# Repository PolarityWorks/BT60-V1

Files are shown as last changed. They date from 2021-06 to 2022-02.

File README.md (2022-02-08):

# BT60 V1

This is the repository of the design files for the Polarity Works [BT60 V1](https://www.polarityworks.com/bt60) containing both schematic and layout files for the soldered and hotswap variants

The files were created in Autodesk Eagle V9.6.2, in the event you do not have a licence for this software we also provide the schematics in PDF format

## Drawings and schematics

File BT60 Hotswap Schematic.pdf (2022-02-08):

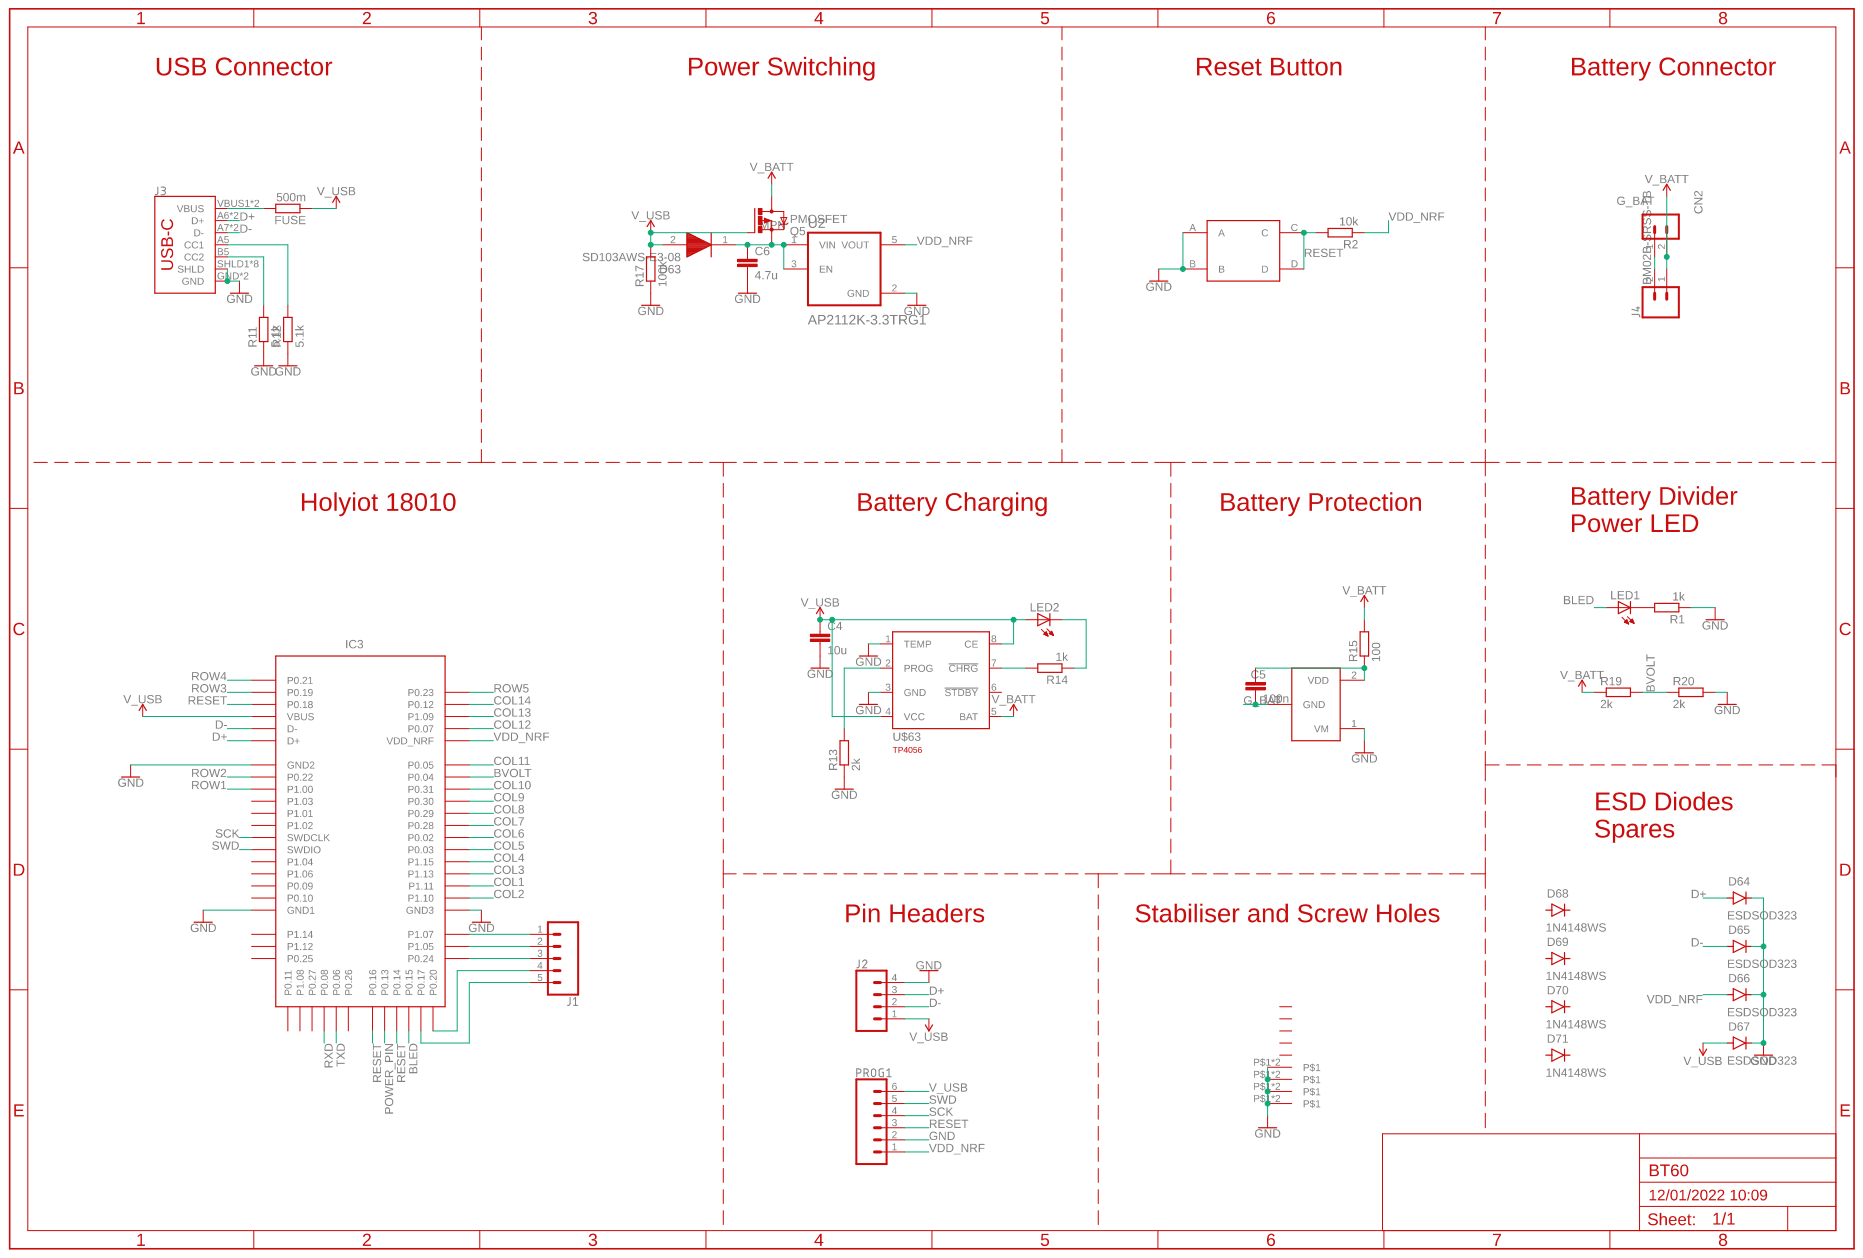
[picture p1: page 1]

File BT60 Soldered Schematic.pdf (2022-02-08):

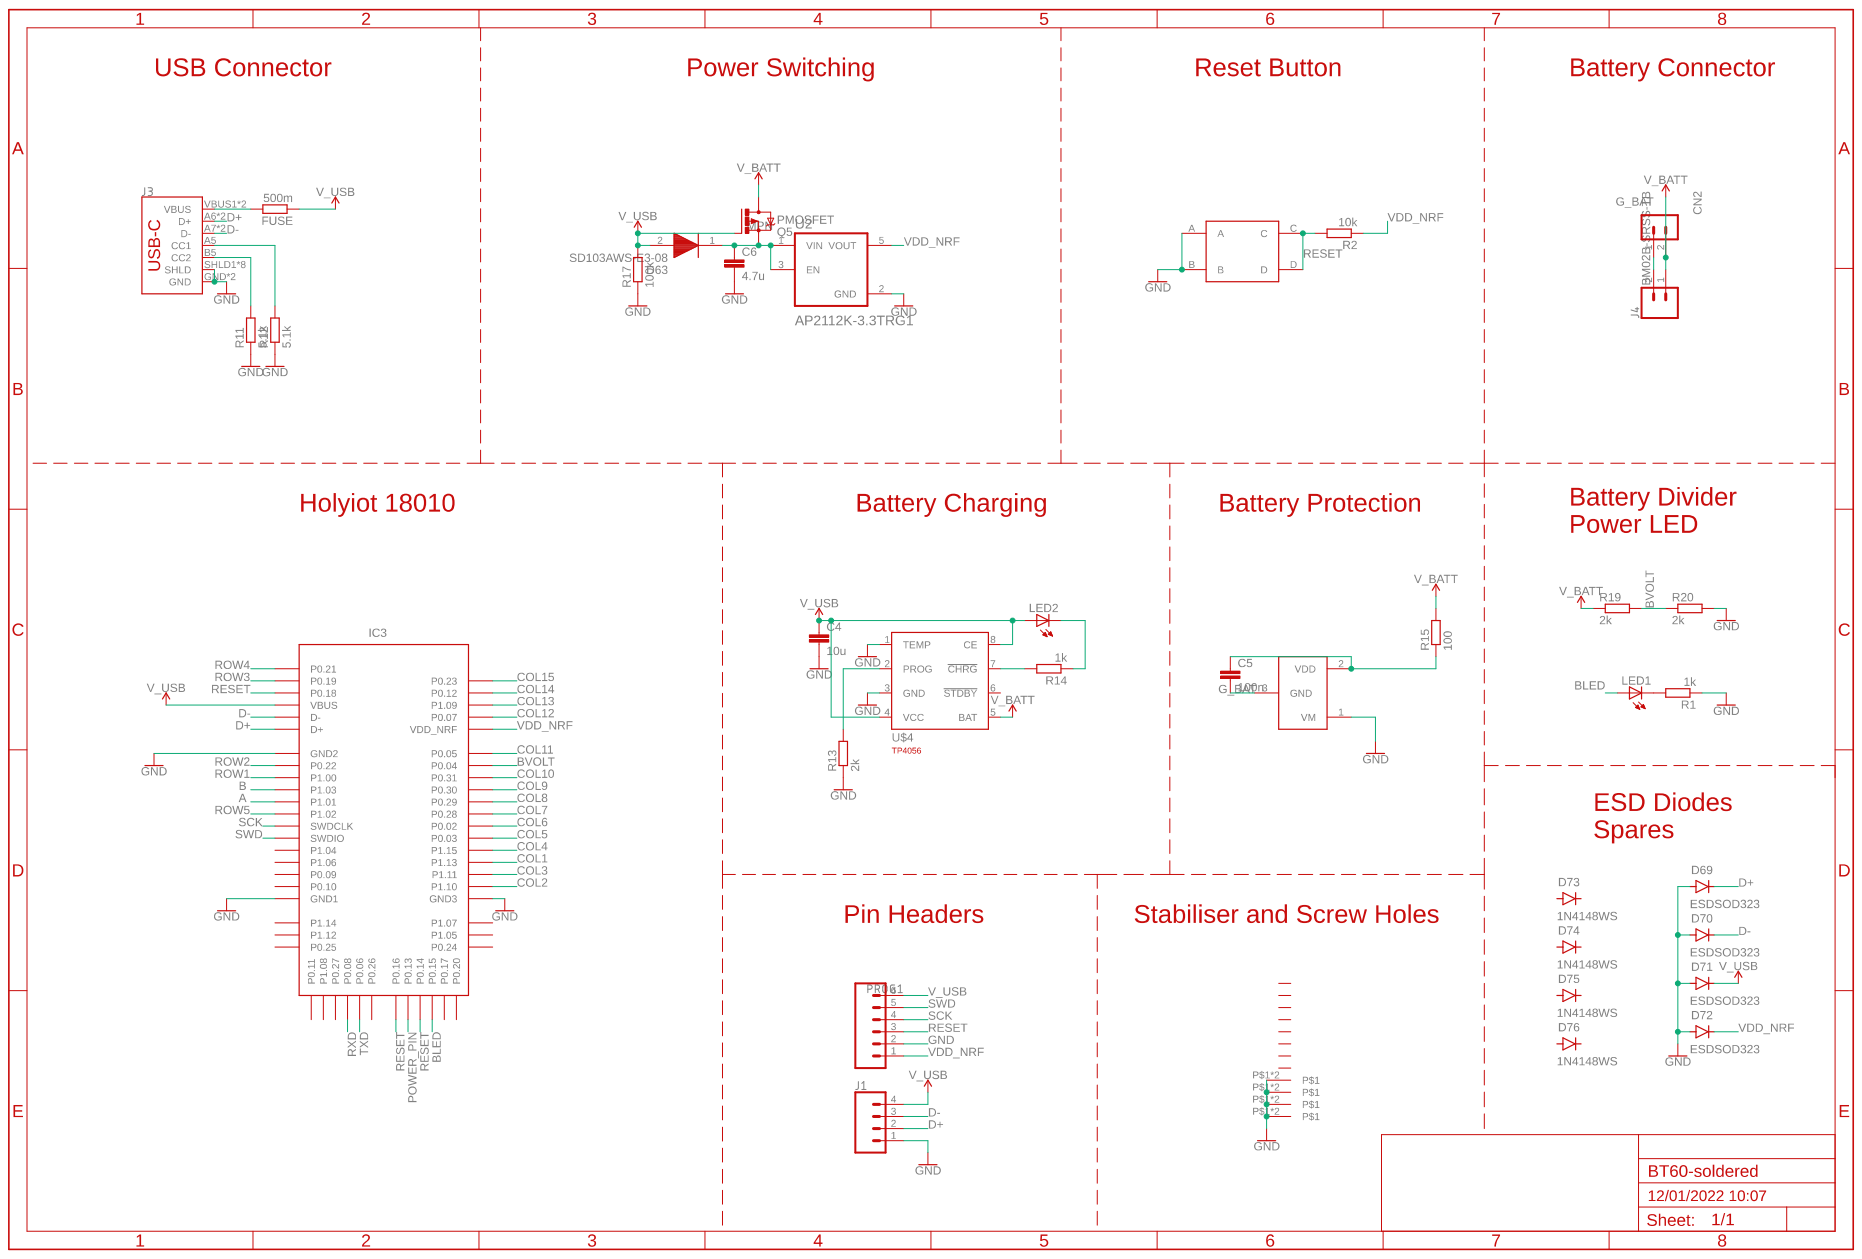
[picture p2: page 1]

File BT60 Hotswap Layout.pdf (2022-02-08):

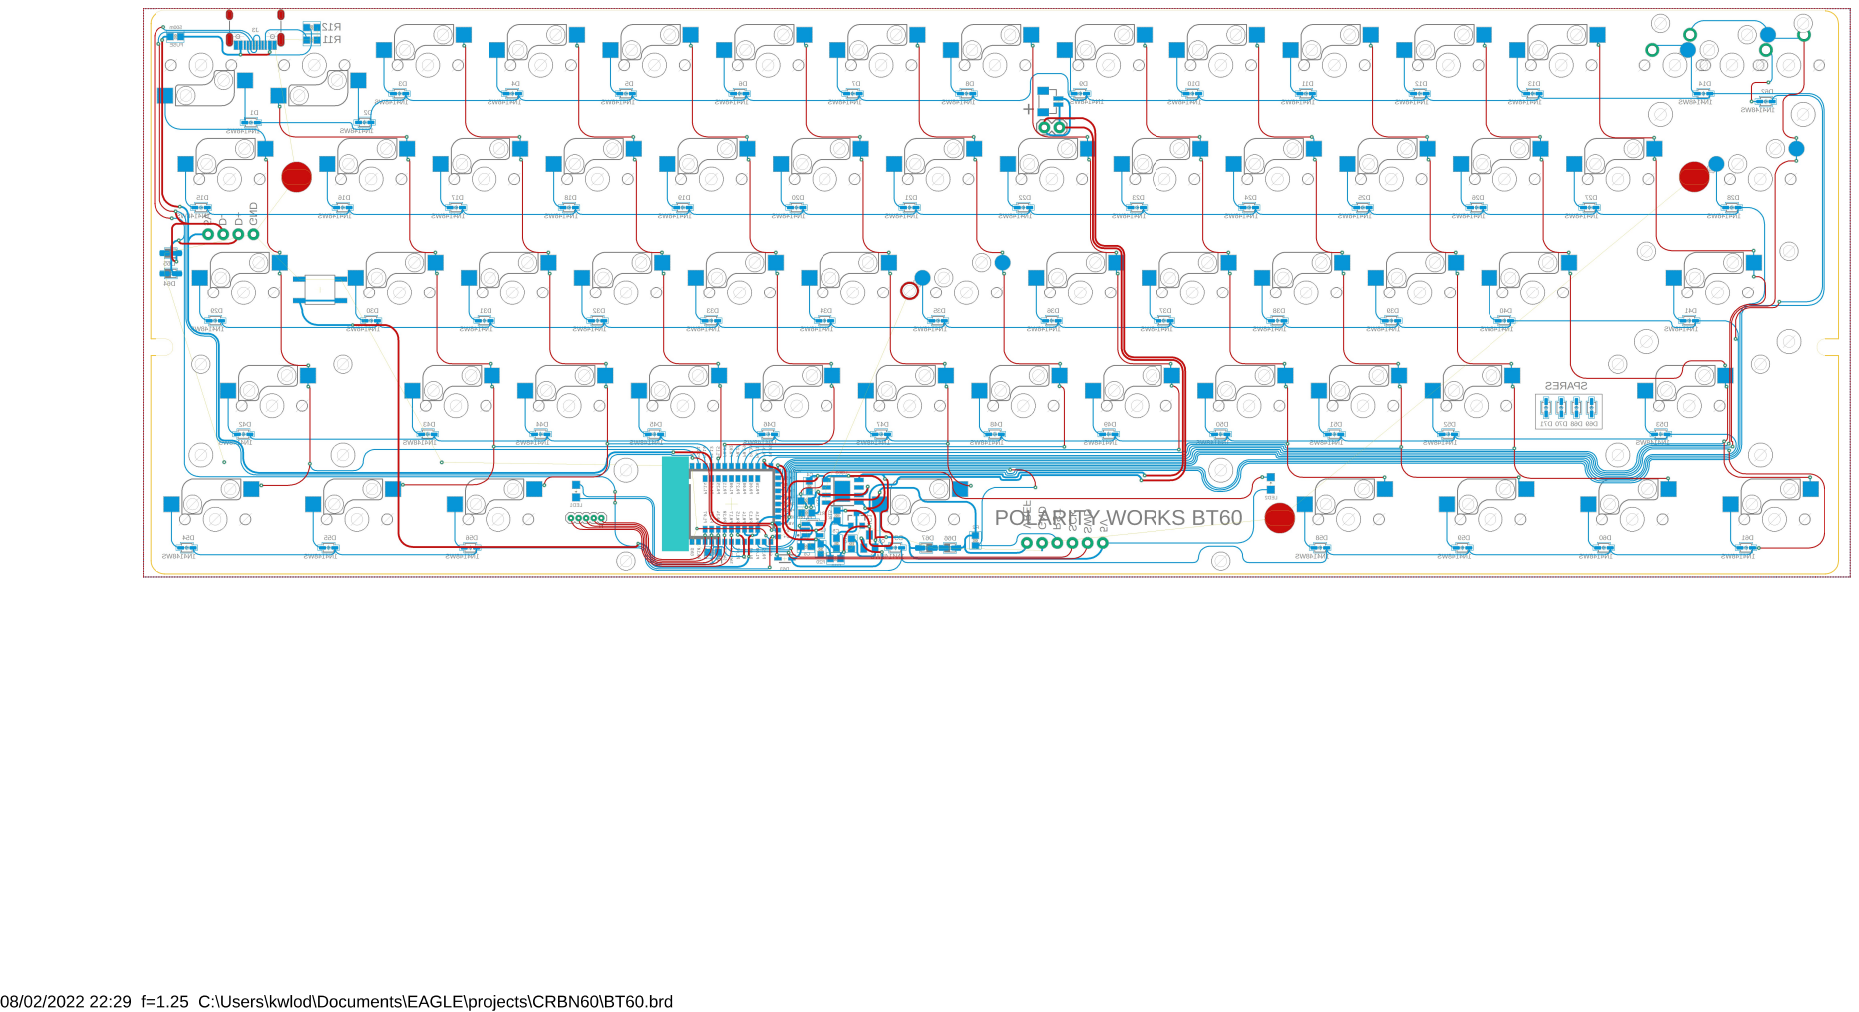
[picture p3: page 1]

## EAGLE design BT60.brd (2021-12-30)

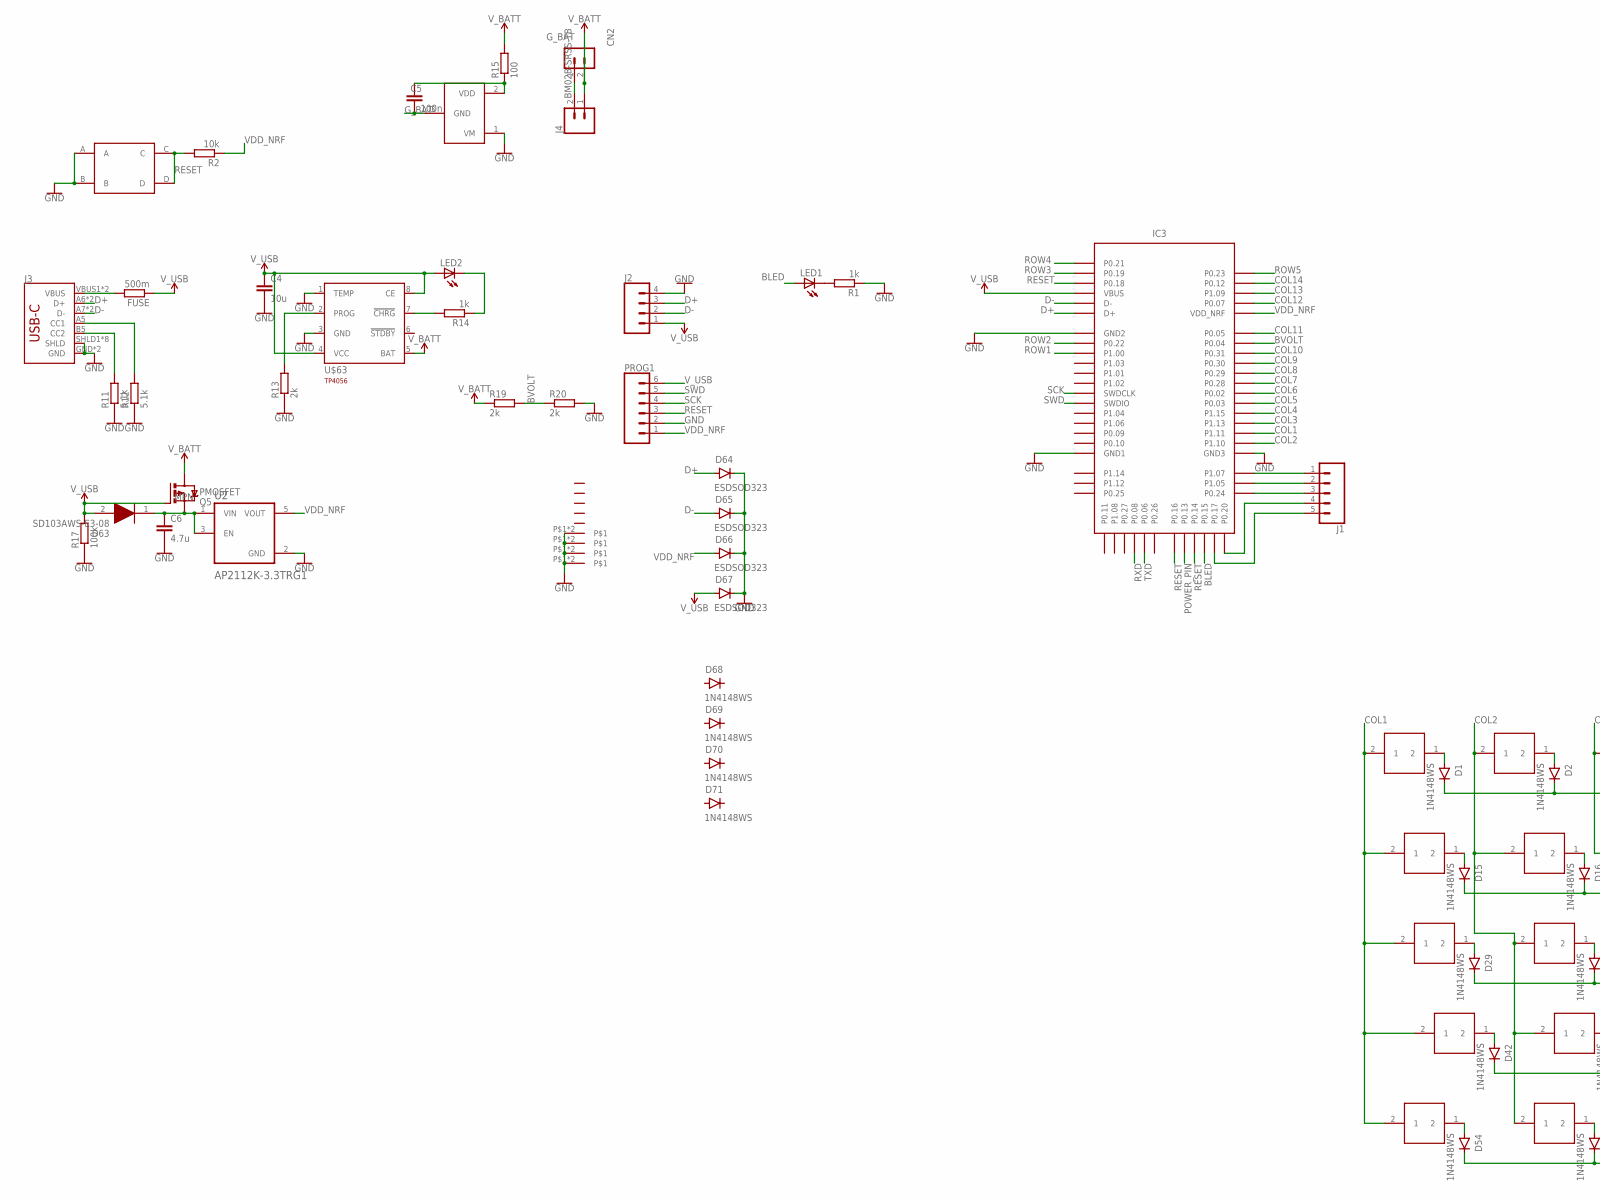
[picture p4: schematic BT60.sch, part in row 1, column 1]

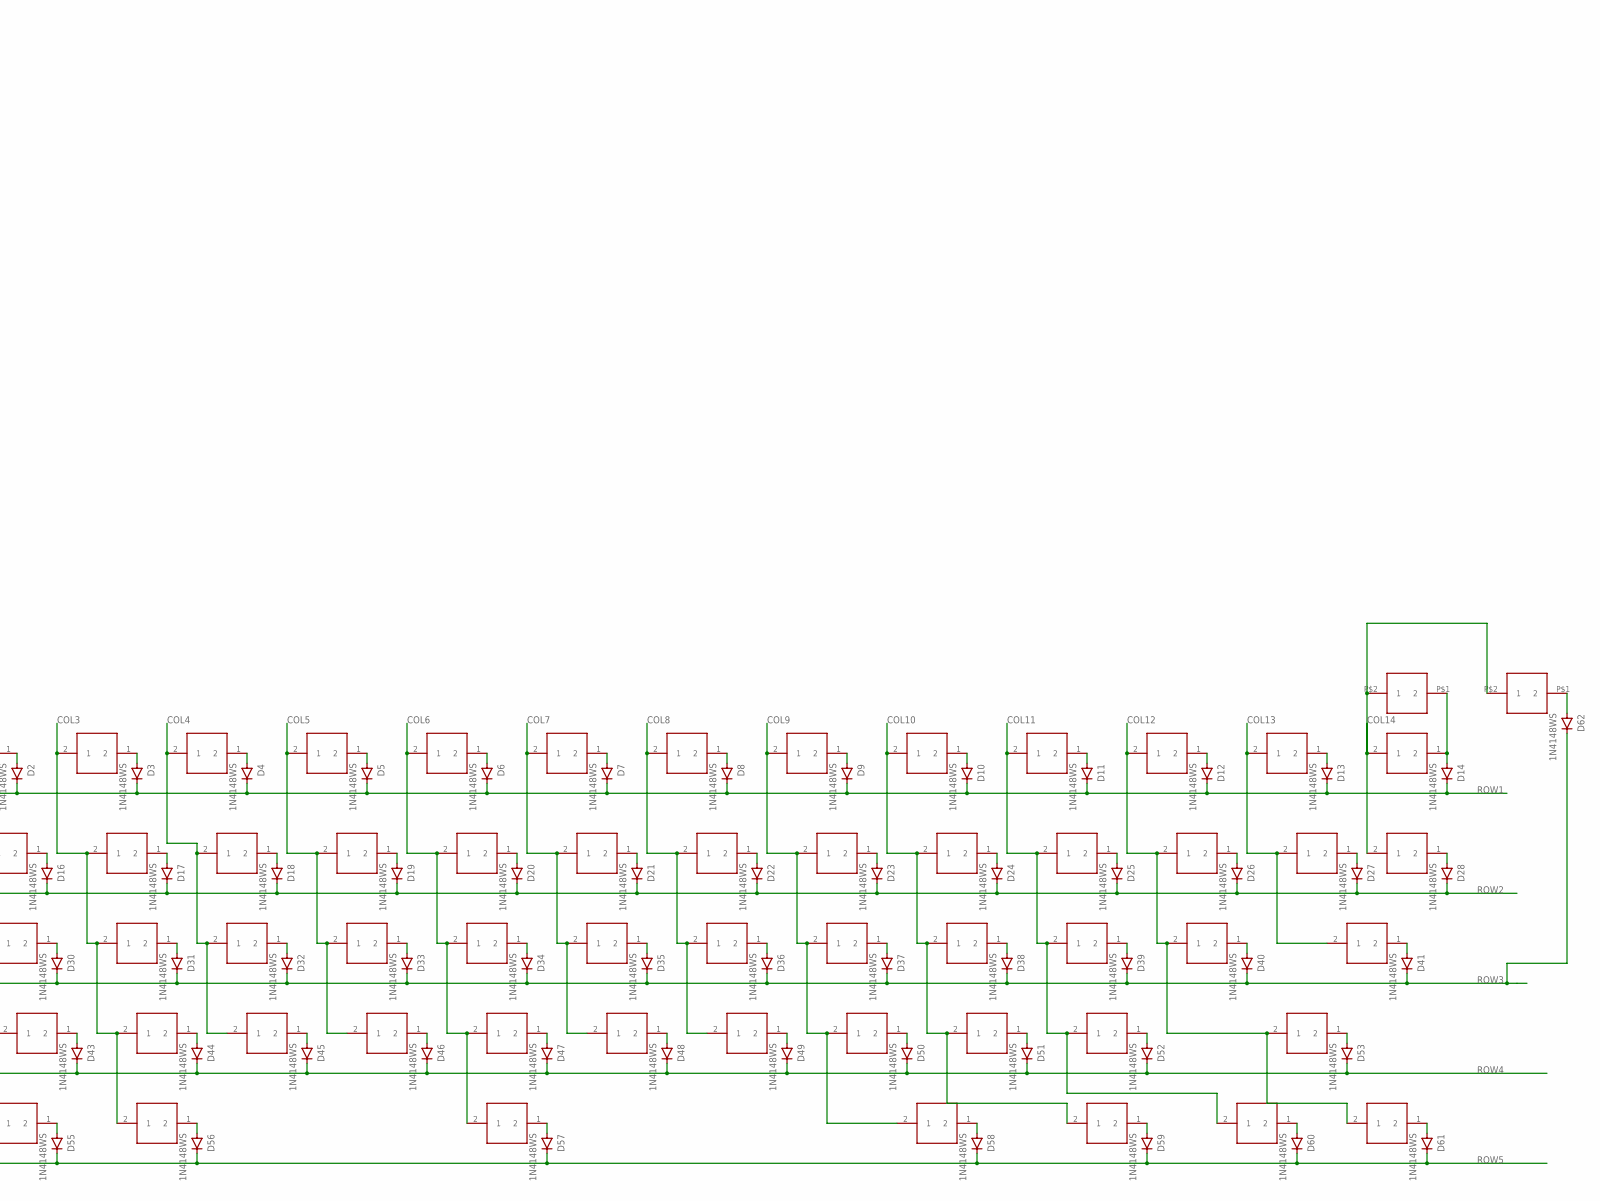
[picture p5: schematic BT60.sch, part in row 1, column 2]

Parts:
C4: 10u; C0603
C5: 100n; C0603
C6: 4.7u; C0603
CN2: BM02B-SRSS-TB
D1, D2, D3, D4, D5, D6, D7, D8, D9, D10, D11, D12, D13, D14, D15, D16, D17, D18, D19, D20, D21, D22, D23, D24, D25, D26, D27, D28, D29, D30, D31, D32, D33, D34, D35, D36, D37, D38, D39, D40, D41, D42, D43, D44, D45, D46, D47, D48, D49, D50, D51, D52, D53, D54, D55, D56, D57, D58, D59, D60, D61, D62, D68, D69, D70, D71: 1N4148WS; SOD-323
D63: SD103AWS-E3-08; SOD2713X115N
D64, D65, D66, D67: ESDSOD323; SOD-323
FUSE: 500m; R0603
IC1: XB3303ASOT23; SOT23-3
IC3: HOLYIOT_18010; PCBCOMPONENT_1
J1: CONN_051.27MM; 1X05_1.27MM
J2: CONN_041X04_NO_SILK; 1X04_NO_SILK
J3: SPARKFUN-CONNECTORS_USB_C16PIN; SPARKFUN-CONNECTORS_USB-C-16P
J4: CONN_02; 1X02
LED1, LED2: LEDCHIPLED_0805; CHIPLED_0805
PROG1: CONN_06NO_SILK_FEMALE_PTH; 1X06_NO_SILK
Q5: PMOSFET; SOT23; MPN SL2301S
R1, R14: 1k; R0603
R2: 10k; R0603
R11, R12: 5.1k; R0603
R13, R19, R20: 2k; R0603
R15: 100; R0603
R17: 100k; R0603
U2: AP2112K-3.3TRG1; SOT95P285X140-5N
U$1, U$2, U$3, U$4, U$5, U$6, U$7, U$8, U$9, U$10, U$11, U$12, U$13, U$15, U$16, U$17, U$18, U$19, U$20, U$21, U$22, U$23, U$24, U$25, U$26, U$27, U$29, U$30, U$31, U$32, U$33, U$34, U$36, U$37, U$38, U$39, U$40, U$41, U$42, U$43, U$44, U$45, U$46, U$47, U$48, U$49, U$50, U$51, U$52, U$53, U$54, U$55, U$56, U$57, U$58, U$59, U$60, U$61: CHERRY
U$14, U$28, U$35: CHERRY_CORNER_OFFED
U$62: SMD-BUTTON
U$63: TP4056SOI8; SOIC8
U$64, U$65, U$67: 2.5MM_ELONGATED
U$66: 2.5MM_HOLE
U$68, U$69, U$70, U$71: STAB-2U
U$72: STAB-6U; STAB-6.25U
U$73, U$74: CHERRY-SOLDER

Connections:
BLED: IC3.P0.15, LED1.A
BVOLT: IC3.P0.04, R19.2, R20.1
COL1: IC3.P1.11, U$1.2 (1), U$15.2 (1), U$29.2 (1), U$42.2 (1), U$54.2 (1)
COL2: IC3.P1.10, U$2.2 (1), U$16.2 (1), U$30.2 (1), U$43.2 (1), U$55.2 (1)
COL3: IC3.P1.13, U$3.2 (1), U$17.2 (1), U$31.2 (1), U$44.2 (1), U$56.2 (1)
COL4: IC3.P1.15, U$4.2 (1), U$18.2 (1), U$32.2 (1), U$45.2 (1)
COL5: IC3.P0.03, U$5.2 (1), U$19.2 (1), U$33.2 (1), U$46.2 (1)
COL6: IC3.P0.02, U$6.2 (1), U$20.2 (1), U$34.2 (1), U$47.2 (1), U$57.2 (1)
COL7: IC3.P0.28, U$7.2 (1), U$21.2 (1), U$35.2 (1), U$48.2 (1)
COL8: IC3.P0.29, U$8.2 (1), U$22.2 (1), U$36.2 (1), U$49.2 (1)
COL9: IC3.P0.30, U$9.2 (1), U$23.2 (1), U$37.2 (1), U$50.2 (1), U$58.2 (1)
COL10: IC3.P0.31, U$10.2 (1), U$24.2 (1), U$38.2 (1), U$51.2 (1), U$59.2 (1)
COL11: IC3.P0.05, U$11.2 (1), U$25.2 (1), U$39.2 (1), U$52.2 (1), U$60.2 (1)
COL12: IC3.P0.07, U$12.2 (1), U$26.2 (1), U$40.2 (1), U$53.2 (1), U$61.2 (1)
COL13: IC3.P1.09, U$13.2 (1), U$27.2 (1), U$41.2 (1)
COL14: IC3.P0.12, U$14.2 (1), U$28.2 (1), U$73.P$2 (1), U$74.P$2 (1)
D+: D64.A, IC3.D+, J2.3, J3.A6 (D+), J3.B6 (D+)
D-: D65.A, IC3.D-, J2.2, J3.A7 (D-), J3.B7 (D-)
GND: C4.2, C6.2, D64.C, D65.C, D66.C, D67.C, IC1.1 (VM), IC3.GND (GND1), IC3.GND1 (GND2), IC3.GND2 (GND3), J2.4, J3.GND, J3.GND2 (GND), J3.SHLD1 (SHLD), J3.SHLD2 (SHLD), J3.SHLD3 (SHLD), J3.SHLD4 (SHLD), J3.SHLD5 (SHLD), J3.SHLD6 (SHLD), J3.SHLD7 (SHLD), J3.SHLD8 (SHLD), PROG1.2, R1.1, R11.1, R12.1, R13.1, R17.1, R20.2, U2.2 (GND), U$62.A, U$62.B, U$63.1 (TEMP), U$63.3 (GND), U$64.P$1, U$64.P$2, U$65.P$1, U$65.P$2, U$66.P$1, U$66.P$2, U$67.P$1, U$67.P$2
G_BAT: C5.2, CN2.1, IC1.3 (GND), J4.2
unnamed: D1.A, U$1.1 (2)
unnamed: LED1.C, R1.2
unnamed: D14.A, U$14.1 (2), U$73.P$1 (2)
unnamed: D13.A, U$13.1 (2)
unnamed: D12.A, U$12.1 (2)
unnamed: D11.A, U$11.1 (2)
unnamed: D10.A, U$10.1 (2)
unnamed: D9.A, U$9.1 (2)
unnamed: D8.A, U$8.1 (2)
unnamed: D7.A, U$7.1 (2)
unnamed: D6.A, U$6.1 (2)
unnamed: D5.A, U$5.1 (2)
unnamed: D4.A, U$4.1 (2)
unnamed: D3.A, U$3.1 (2)
unnamed: D2.A, U$2.1 (2)
unnamed: D15.A, U$15.1 (2)
unnamed: IC3.P1.07, J1.1
unnamed: D28.A, U$28.1 (2)
unnamed: D27.A, U$27.1 (2)
unnamed: D26.A, U$26.1 (2)
unnamed: D25.A, U$25.1 (2)
unnamed: D24.A, U$24.1 (2)
unnamed: D23.A, U$23.1 (2)
unnamed: D22.A, U$22.1 (2)
unnamed: D21.A, U$21.1 (2)
unnamed: D20.A, U$20.1 (2)
unnamed: D19.A, U$19.1 (2)
unnamed: D18.A, U$18.1 (2)
unnamed: D17.A, U$17.1 (2)
unnamed: D16.A, U$16.1 (2)
unnamed: D29.A, U$29.1 (2)
unnamed: IC3.P1.05, J1.2
unnamed: D41.A, U$41.1 (2)
unnamed: D40.A, U$40.1 (2)
unnamed: D39.A, U$39.1 (2)
unnamed: D38.A, U$38.1 (2)
unnamed: D37.A, U$37.1 (2)
unnamed: D36.A, U$36.1 (2)
unnamed: D35.A, U$35.1 (2)
unnamed: D34.A, U$34.1 (2)
unnamed: D33.A, U$33.1 (2)
unnamed: D32.A, U$32.1 (2)
unnamed: D31.A, U$31.1 (2)
unnamed: D30.A, U$30.1 (2)
unnamed: D42.A, U$42.1 (2)
unnamed: IC3.P0.24, J1.3
unnamed: D53.A, U$53.1 (2)
unnamed: D52.A, U$52.1 (2)
unnamed: D51.A, U$51.1 (2)
unnamed: D50.A, U$50.1 (2)
unnamed: D49.A, U$49.1 (2)
unnamed: D48.A, U$48.1 (2)
unnamed: D47.A, U$47.1 (2)
unnamed: D46.A, U$46.1 (2)
unnamed: D45.A, U$45.1 (2)
unnamed: D44.A, U$44.1 (2)
unnamed: D43.A, U$43.1 (2)
unnamed: D54.A, U$54.1 (2)
unnamed: IC3.P0.20, J1.4
unnamed: D61.A, U$61.1 (2)
unnamed: D60.A, U$60.1 (2)
unnamed: D59.A, U$59.1 (2)
unnamed: D58.A, U$58.1 (2)
unnamed: D57.A, U$57.1 (2)
unnamed: D56.A, U$56.1 (2)
unnamed: D55.A, U$55.1 (2)
unnamed: IC3.P0.17, J1.5
unnamed: D62.A, U$74.P$1 (2)
unnamed: C5.1, IC1.2 (VDD), R15.1
unnamed: FUSE.2, J3.VBUS1 (VBUS), J3.VBUS2 (VBUS)
unnamed: J3.B5 (CC2), R11.2
unnamed: J3.A5 (CC1), R12.2
unnamed: R13.2, U$63.2 (PROG)
unnamed: LED2.C, R14.1
unnamed: R14.2, U$63.7 (!CHRG)
unnamed: C6.1, D63.1 (K), Q5.2 (S), U2.1 (VIN), U2.3 (EN)
POWER_PIN: IC3.P0.13
RESET: IC3.P0.14, IC3.P0.16, IC3.P0.18, PROG1.3, R2.2, U$62.C, U$62.D
ROW1: D1.C, D2.C, D3.C, D4.C, D5.C, D6.C, D7.C, D8.C, D9.C, D10.C, D11.C, D12.C, D13.C, D14.C, IC3.P1.00
ROW2: D15.C, D16.C, D17.C, D18.C, D19.C, D20.C, D21.C, D22.C, D23.C, D24.C, D25.C, D26.C, D27.C, D28.C, IC3.P0.22
ROW3: D29.C, D30.C, D31.C, D32.C, D33.C, D34.C, D35.C, D36.C, D37.C, D38.C, D39.C, D40.C, D41.C, D62.C, IC3.P0.19
ROW4: D42.C, D43.C, D44.C, D45.C, D46.C, D47.C, D48.C, D49.C, D50.C, D51.C, D52.C, D53.C, IC3.P0.21
ROW5: D54.C, D55.C, D56.C, D57.C, D58.C, D59.C, D60.C, D61.C, IC3.P0.23
RXD: IC3.P0.08
SCK: IC3.SWDCLK, PROG1.4
SWD: IC3.SWDIO, PROG1.5
TXD: IC3.P0.06
VDD_NRF: D66.A, IC3.VDD_NRF, PROG1.1, R2.1, U2.5 (VOUT)
V_BATT: CN2.2, J4.1, Q5.3 (D), R15.2, R19.1, U$63.5 (BAT)
V_USB: C4.1, D63.2 (A), D67.A, FUSE.1, IC3.VBUS, J2.1, LED2.A, PROG1.6, Q5.1 (G), R17.2, U$63.4 (VCC), U$63.8 (CE)

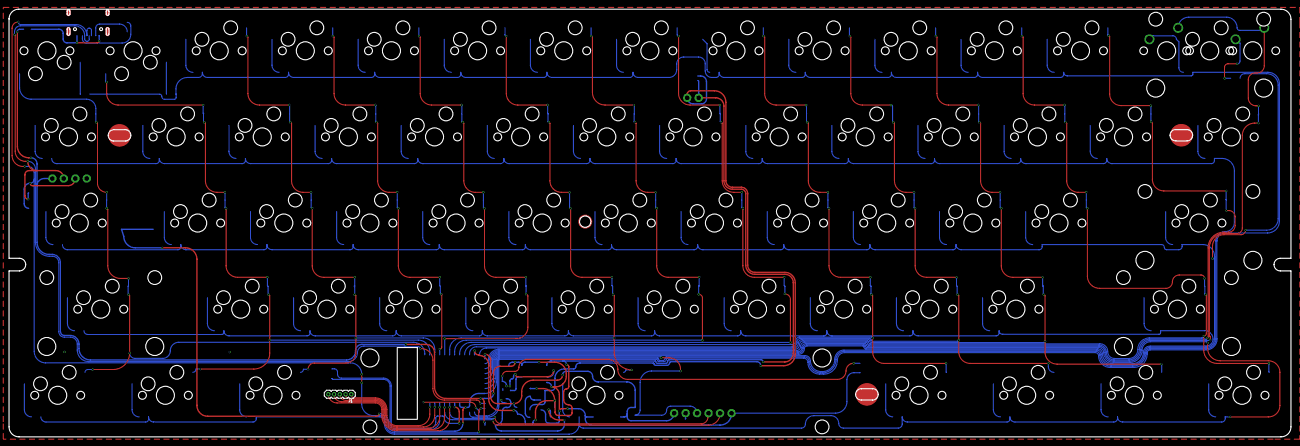
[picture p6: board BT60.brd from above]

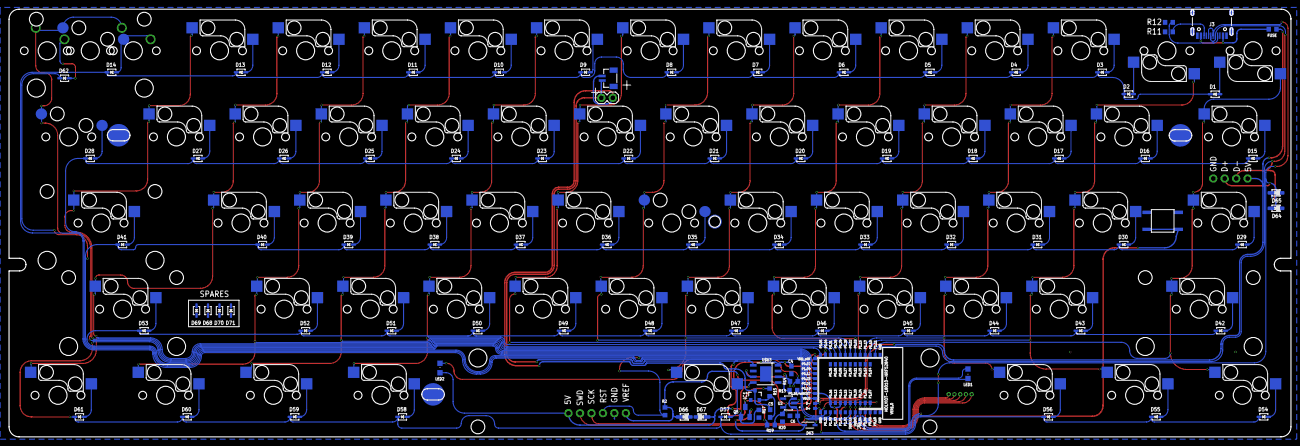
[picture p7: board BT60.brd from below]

Board: 2 copper layers, 283.5 x 94.6 mm, 171 parts (96 on the bottom side), 107 nets.

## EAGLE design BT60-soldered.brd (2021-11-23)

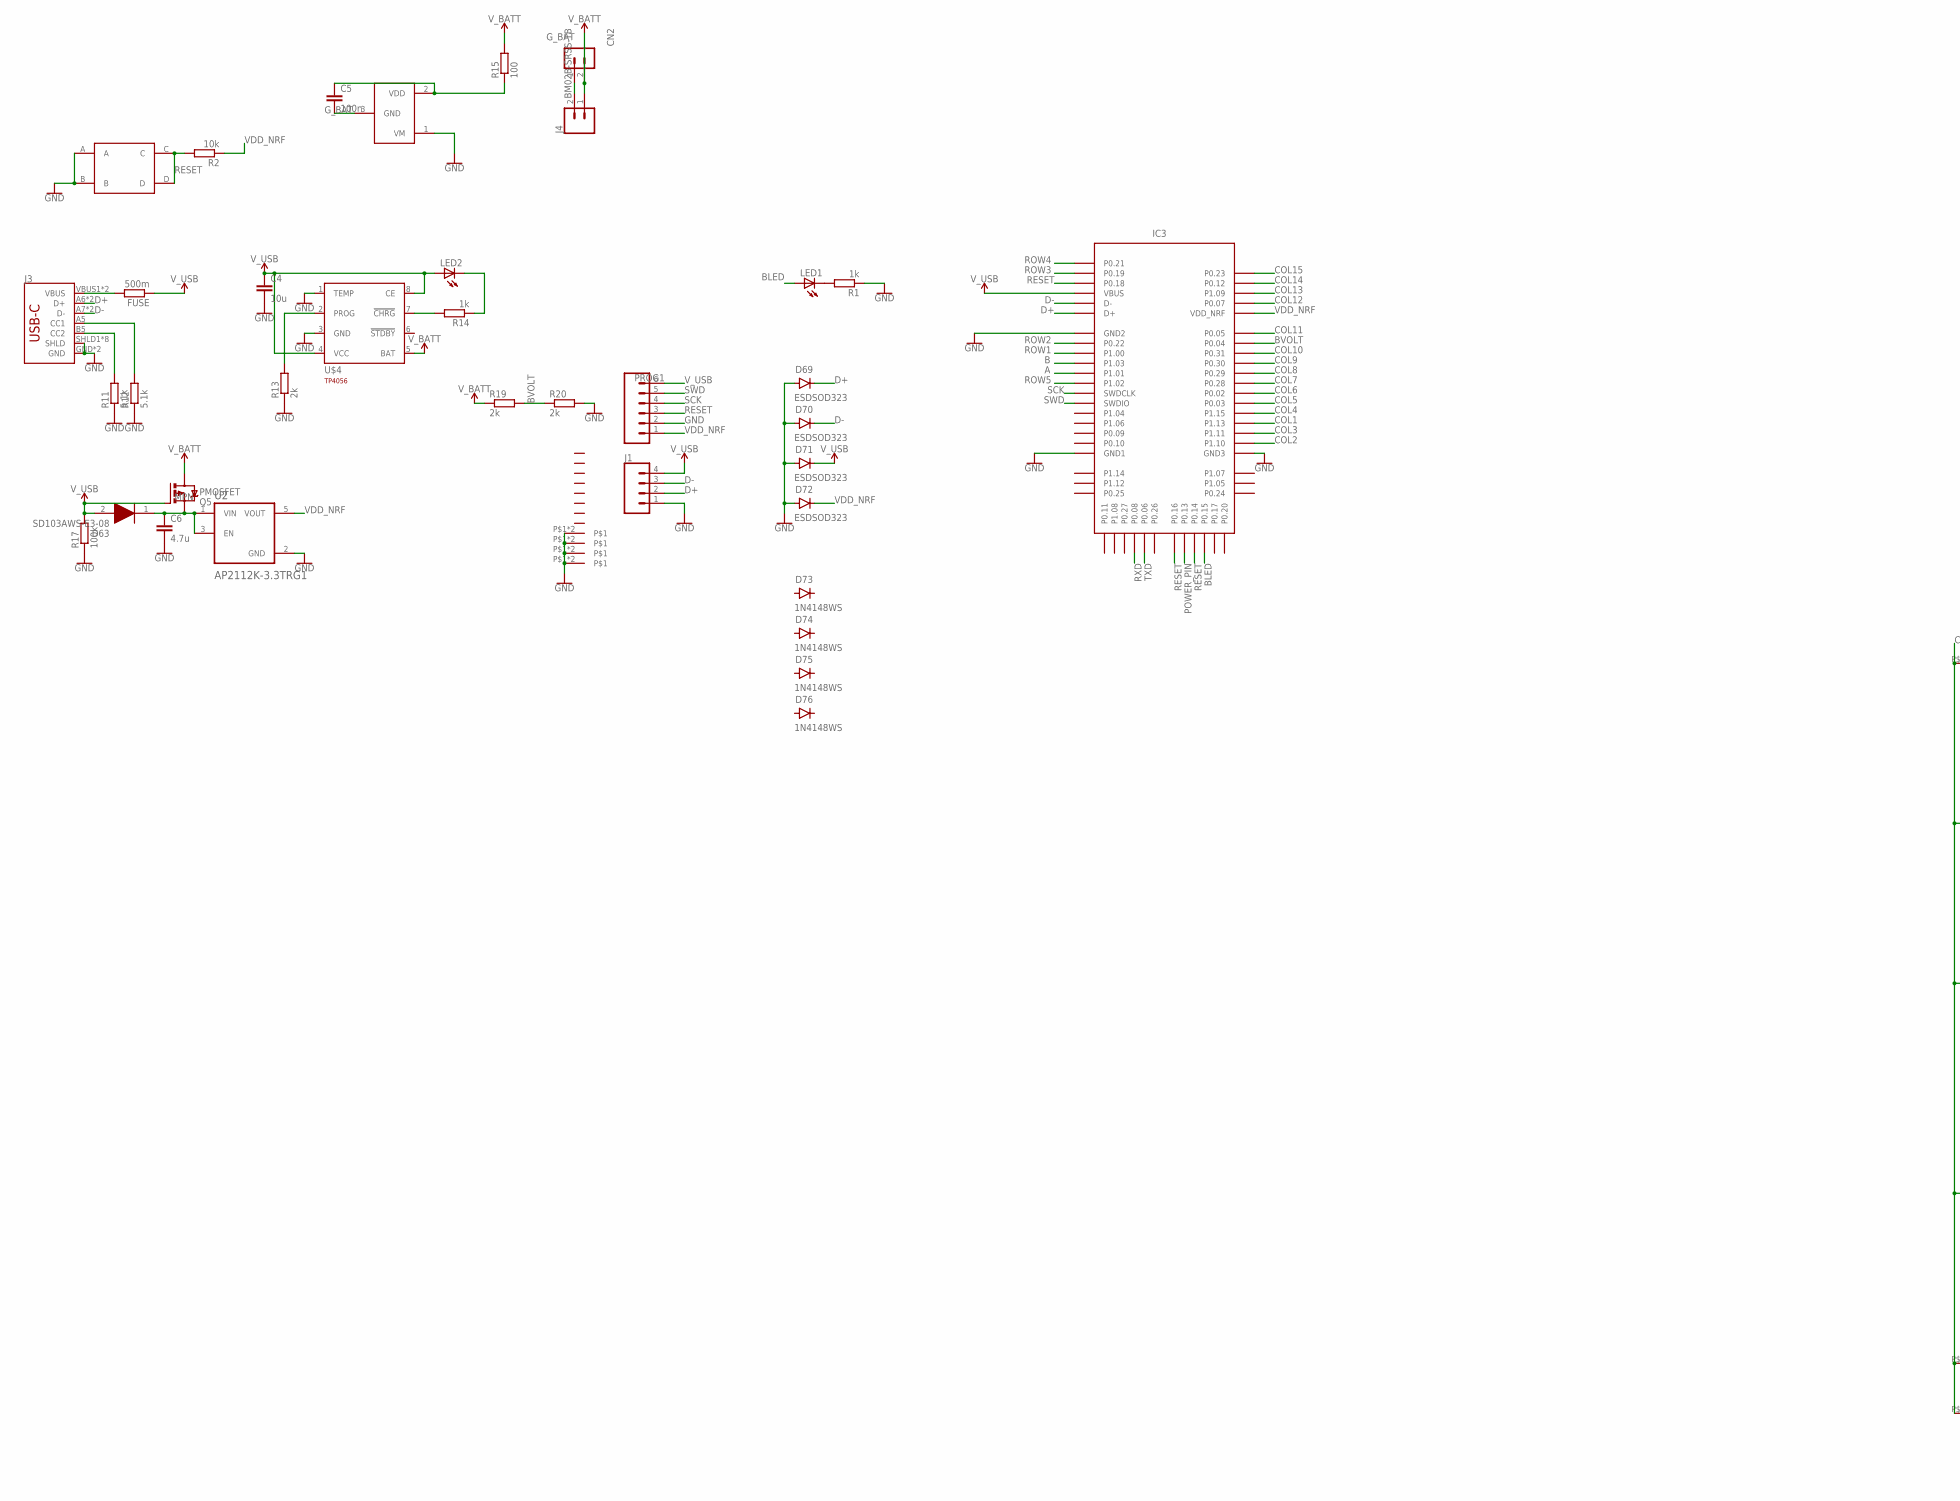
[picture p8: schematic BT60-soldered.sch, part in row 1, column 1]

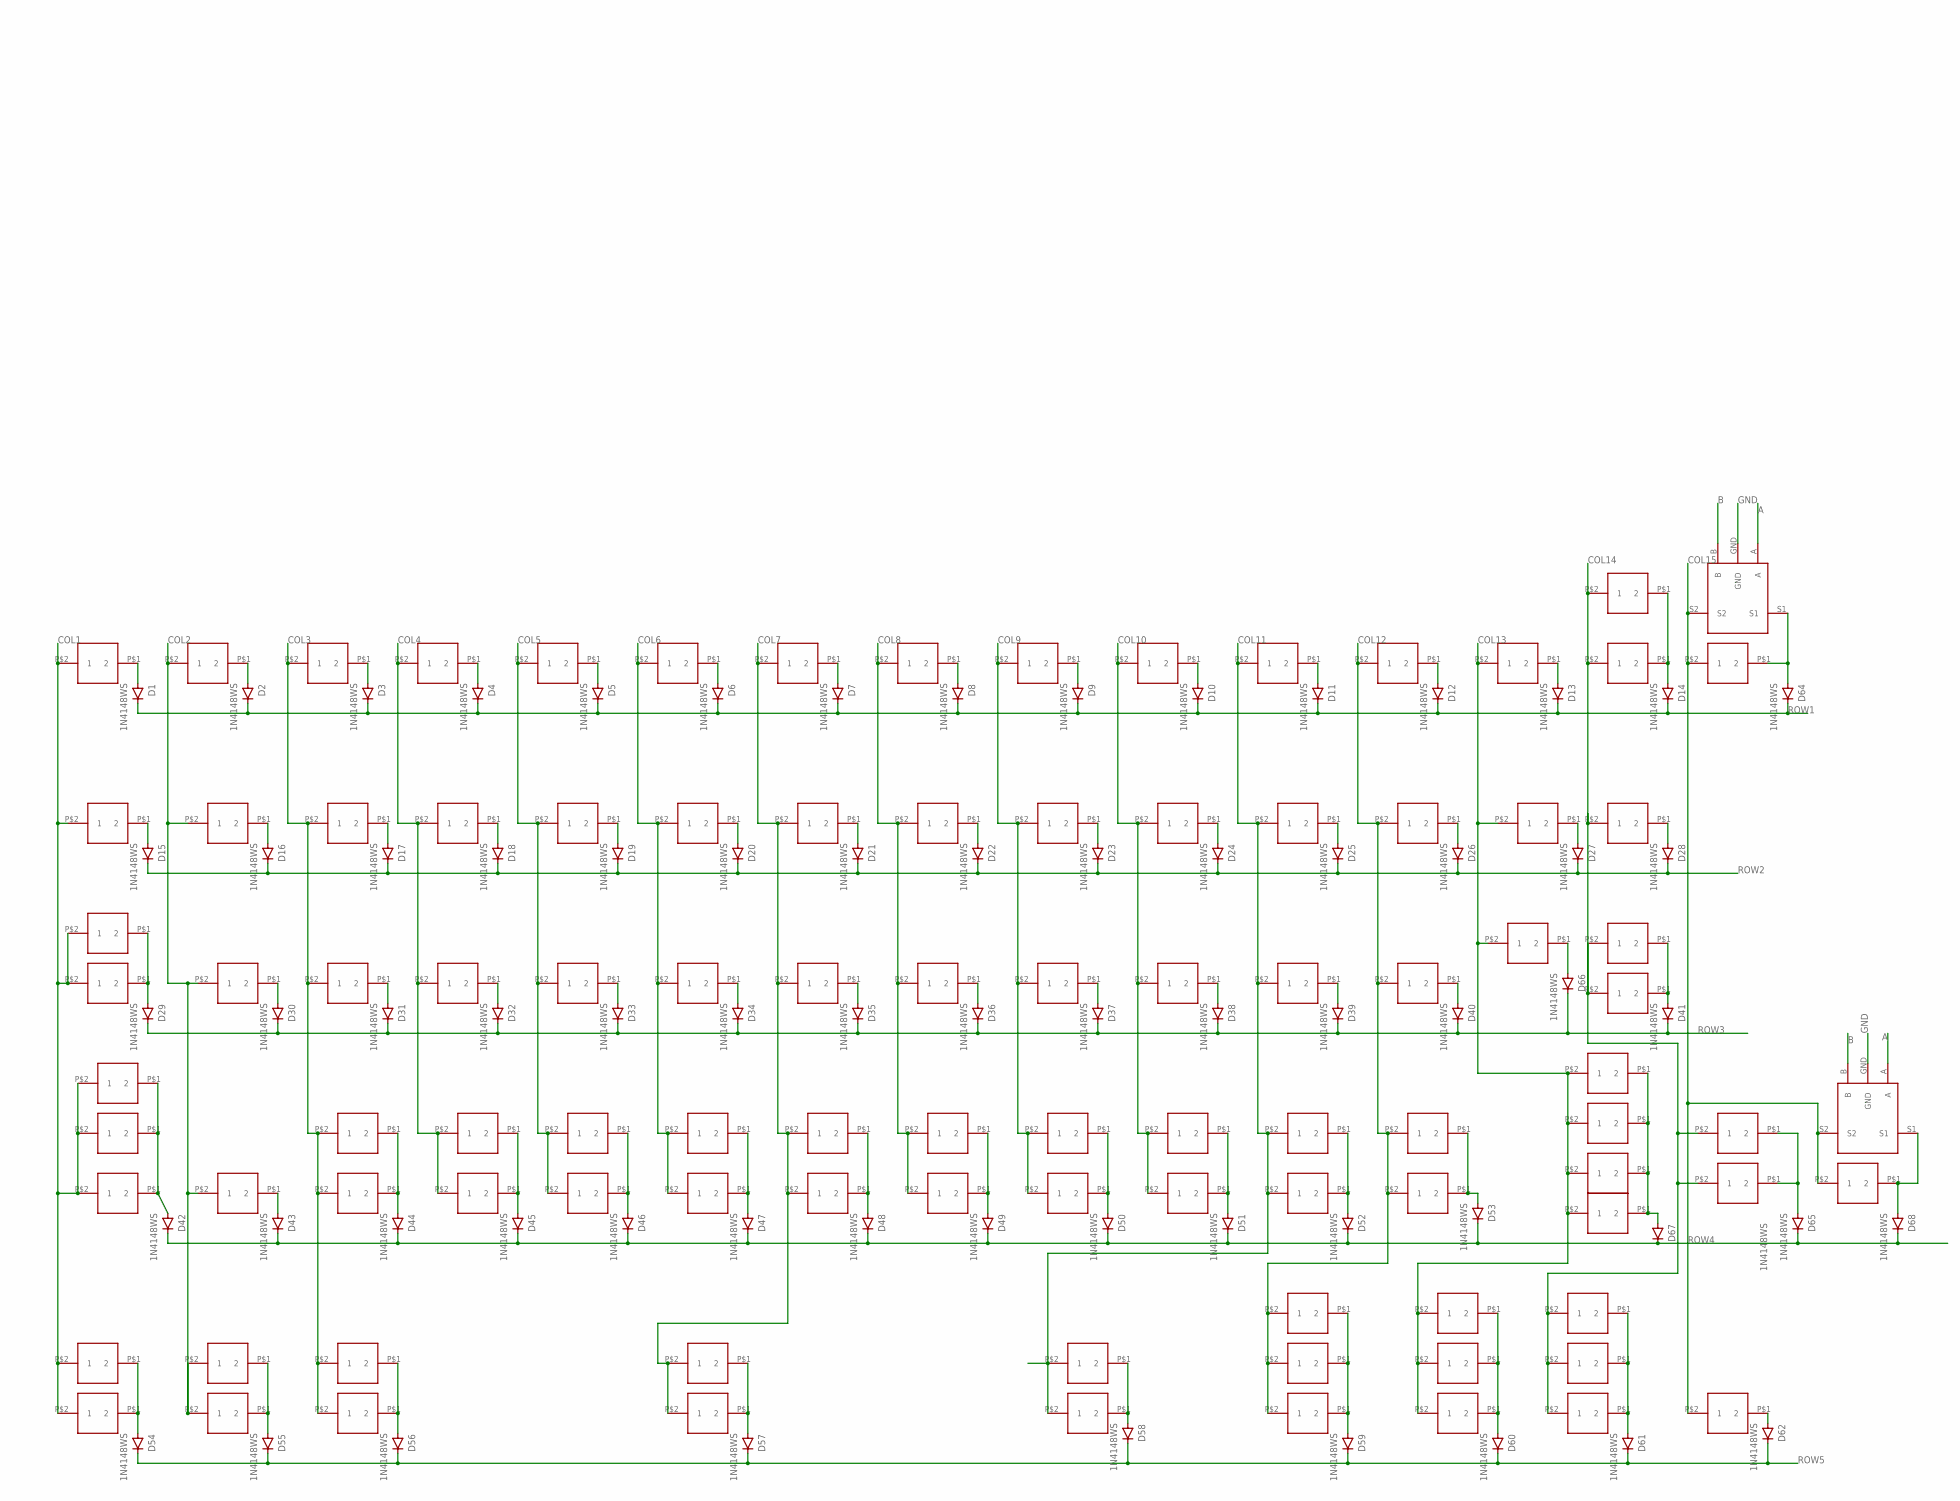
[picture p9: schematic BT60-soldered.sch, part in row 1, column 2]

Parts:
0, 1, 1U_1, 1U_2, 1U_3, 1U_4, 1U_5, 2, 3, 4, 5, 6, 7, 8, 9, ., ._1: CHERRY-SOLDER
#_ISO: CHERRY-SOLDER
': CHERRY-SOLDER
,: CHERRY-SOLDER
,_1: CHERRY-SOLDER
-: CHERRY-SOLDER
/: CHERRY-SOLDER
/_1: CHERRY-SOLDER
=: CHERRY-SOLDER
A: CHERRY-SOLDER
B: CHERRY-SOLDER
BS: CHERRY-SOLDER
B_1: CHERRY-SOLDER
C: CHERRY-SOLDER
C4: 10u; C0603
C5: 100n; C0603
C6: 4.7u; C0603
CAPS: CHERRY-SOLDER
CAPS_STEP: CHERRY-SOLDER
CN2: BM02B-SRSS-TB
COLON: CHERRY-SOLDER
C_1: CHERRY-SOLDER
D: CHERRY-SOLDER
D1, D2, D3, D4, D5, D6, D7, D8, D9, D10, D11, D12, D13, D14, D15, D16, D17, D18, D19, D20, D21, D22, D23, D24, D25, D26, D27, D28, D29, D30, D31, D32, D33, D34, D35, D36, D37, D38, D39, D40, D41, D42, D43, D44, D45, D46, D47, D48, D49, D50, D51, D52, D53, D54, D55, D56, D57, D58, D59, D60, D61, D62, D64, D65, D66, D67, D68, D73, D74, D75, D76: 1N4148WS; SOD-323
D63: SD103AWS-E3-08; SOD2713X115N
D69, D70, D71, D72: ESDSOD323; SOD-323
E: CHERRY-SOLDER
ENTER: CHERRY-SOLDER
ESC: CHERRY-SOLDER
EXTRA_1U_LEFT: CHERRY-SOLDER
F: CHERRY-SOLDER
FN: CHERRY-SOLDER
FUSE: 500m; R0603
G: CHERRY-SOLDER
H: CHERRY-SOLDER
I: CHERRY-SOLDER
IC3: HOLYIOT_18010; PCBCOMPONENT_1
ISO_#: CHERRY-SOLDER
ISO_ENTER: CHERRY-SOLDER
J: CHERRY-SOLDER
J1: CONN_041X04_NO_SILK; 1X04_NO_SILK
J3: SPARKFUN-CONNECTORS_USB_C16PIN; SPARKFUN-CONNECTORS_USB-C-16P
J4: CONN_02; 1X02
K: CHERRY-SOLDER
L: CHERRY-SOLDER
LALT: CHERRY-SOLDER
LALT_1.5U: CHERRY-SOLDER
LCTRL: CHERRY-SOLDER
LCTRL_1.5U: CHERRY-SOLDER
LED1, LED2: LEDCHIPLED_0805; CHIPLED_0805
LWIN: CHERRY-SOLDER
LWIN_1U: CHERRY-SOLDER
L_1.25U_SHIFT, L_2U_SHIFT: CHERRY-SOLDER
L_SHIFT: CHERRY-SOLDER
M: CHERRY-SOLDER
MENU: CHERRY-SOLDER
MENU_1U: CHERRY-SOLDER
M_1: CHERRY-SOLDER
N: CHERRY-SOLDER
N_1: CHERRY-SOLDER
O: CHERRY-SOLDER
P: CHERRY-SOLDER
PROG1: CONN_06NO_SILK_FEMALE_PTH; 1X06_NO_SILK
Q: CHERRY-SOLDER
Q5: PMOSFET; SOT23; MPN SL2301S
R: CHERRY-SOLDER
R1, R14: 1k; R0603
R2: 10k; R0603
R11, R12: 5.1k; R0603
R13, R19, R20: 2k; R0603
R15: 100; R0603
R17: 100k; R0603
RALT: CHERRY-SOLDER
RCTRL: CHERRY-SOLDER
R_ALT_1.5: CHERRY-SOLDER
R_CTRL_1.5U: CHERRY-SOLDER
R_SHIFT: CHERRY-SOLDER
R_SHIFT_1.75U_LEFT, R_SHIFT_1.75U_RIGHT: CHERRY-SOLDER
S: CHERRY-SOLDER
SPACE_6.25U, SPACE_7U: CHERRY-SOLDER
SPLIT_BS_1, SPLIT_BS_2: CHERRY-SOLDER
T: CHERRY-SOLDER
TAB: CHERRY-SOLDER
U: CHERRY-SOLDER
U2: AP2112K-3.3TRG1; SOT95P285X140-5N
U$1, U$2: CHERRY-ENCODER
U$3: XB3303ASOT23; SOT23-3
U$4: TP4056SOI8; SOIC8
U$62: SMD-BUTTON
U$64, U$65, U$66, U$67: 2.5MM_ELONGATED
U$68, U$69, U$70, U$71, U$83, U$108: STAB-2U
U$72: STAB-6U; STAB-6.25U
U$91: STAB-7U
UP: CHERRY-SOLDER
V: CHERRY-SOLDER
V_1: CHERRY-SOLDER
W: CHERRY-SOLDER
X, X5U_1, X5U_2: CHERRY-SOLDER
X_1: CHERRY-SOLDER
Y: CHERRY-SOLDER
Z: CHERRY-SOLDER
Z_1: CHERRY-SOLDER
[: CHERRY-SOLDER
\: CHERRY-SOLDER
]: CHERRY-SOLDER

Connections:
A: IC3.P1.01, U$1.A, U$2.A
B: IC3.P1.03, U$1.B, U$2.B
BLED: IC3.P0.15, LED1.A
BVOLT: IC3.P0.04, R19.2, R20.1
COL1: CAPS.P$2 (1), CAPS_STEP.P$2 (1), ESC.P$2 (1), IC3.P1.13, LCTRL.P$2 (1), LCTRL_1.5U.P$2 (1), L_1.25U_SHIFT.P$2 (1), L_2U_SHIFT.P$2 (1), L_SHIFT.P$2 (1), TAB.P$2 (1)
COL2: 1.P$2 (1), #_ISO.P$2 (1), A.P$2 (1), IC3.P1.10, LWIN.P$2 (1), LWIN_1U.P$2 (1), Q.P$2 (1)
COL3: 2.P$2 (1), IC3.P1.11, LALT.P$2 (1), LALT_1.5U.P$2 (1), S.P$2 (1), W.P$2 (1), Z.P$2 (1), Z_1.P$2 (1)
COL4: 3.P$2 (1), D.P$2 (1), E.P$2 (1), IC3.P1.15, X.P$2 (1), X_1.P$2 (1)
COL5: 4.P$2 (1), C.P$2 (1), C_1.P$2 (1), F.P$2 (1), IC3.P0.03, R.P$2 (1)
COL6: 5.P$2 (1), G.P$2 (1), IC3.P0.02, T.P$2 (1), V.P$2 (1), V_1.P$2 (1)
COL7: 6.P$2 (1), B.P$2 (1), B_1.P$2 (1), H.P$2 (1), IC3.P0.28, SPACE_6.25U.P$2 (1), SPACE_7U.P$2 (1), Y.P$2 (1)
COL8: 7.P$2 (1), IC3.P0.29, J.P$2 (1), N.P$2 (1), N_1.P$2 (1), U.P$2 (1)
COL9: 8.P$2 (1), I.P$2 (1), IC3.P0.30, K.P$2 (1), M.P$2 (1), M_1.P$2 (1)
COL10: 9.P$2 (1), ,.P$2 (1), ,_1.P$2 (1), IC3.P0.31, L.P$2 (1), O.P$2 (1)
COL11: 0.P$2 (1), 1U_1.P$2 (1), ..P$2 (1), ._1.P$2 (1), COLON.P$2 (1), IC3.P0.05, P.P$2 (1), RALT.P$2 (1)
COL12: 1U_2.P$2 (1), '.P$2 (1), -.P$2 (1), /.P$2 (1), /_1.P$2 (1), IC3.P0.07, MENU.P$2 (1), R_ALT_1.5.P$2 (1), [.P$2 (1)
COL13: 1U_3.P$2 (1), =.P$2 (1), EXTRA_1U_LEFT.P$2 (1), IC3.P1.09, ISO_#.P$2 (1), MENU_1U.P$2 (1), RCTRL.P$2 (1), R_SHIFT.P$2 (1), R_SHIFT_1.75U_LEFT.P$2 (1), UP.P$2 (1), ].P$2 (1)
COL14: 1U_4.P$2 (1), BS.P$2 (1), ENTER.P$2 (1), FN.P$2 (1), IC3.P0.12, ISO_ENTER.P$2 (1), R_CTRL_1.5U.P$2 (1), R_SHIFT_1.75U_RIGHT.P$2 (1), SPLIT_BS_1.P$2 (1), X5U_1.P$2 (1), \.P$2 (1)
COL15: 1U_5.P$2 (1), IC3.P0.23, SPLIT_BS_2.P$2 (1), U$1.S2, U$2.S2, X5U_2.P$2 (1)
D+: D69.C, IC3.D+, J1.2, J3.A6 (D+), J3.B6 (D+)
D-: D70.C, IC3.D-, J1.3, J3.A7 (D-), J3.B7 (D-)
GND: C4.2, C6.2, D69.A, D70.A, D71.A, D72.A, IC3.GND (GND1), IC3.GND1 (GND2), IC3.GND2 (GND3), J1.1, J3.GND, J3.GND2 (GND), J3.SHLD1 (SHLD), J3.SHLD2 (SHLD), J3.SHLD3 (SHLD), J3.SHLD4 (SHLD), J3.SHLD5 (SHLD), J3.SHLD6 (SHLD), J3.SHLD7 (SHLD), J3.SHLD8 (SHLD), PROG1.2, R1.1, R11.1, R12.1, R13.1, R17.1, R20.2, U2.2 (GND), U$1.GND, U$2.GND, U$3.1 (VM), U$4.1 (TEMP), U$4.3 (GND), U$62.A, U$62.B, U$64.P$1, U$64.P$2, U$65.P$1, U$65.P$2, U$66.P$1, U$66.P$2, U$67.P$1, U$67.P$2
G_BAT: C5.2, CN2.1, J4.2, U$3.3 (GND)
unnamed: D1.A, ESC.P$1 (2)
unnamed: LED1.C, R1.2
unnamed: 1U_5.P$1 (2), D62.A
unnamed: =.P$1 (2), D13.A
unnamed: -.P$1 (2), D12.A
unnamed: 0.P$1 (2), D11.A
unnamed: 9.P$1 (2), D10.A
unnamed: 8.P$1 (2), D9.A
unnamed: 7.P$1 (2), D8.A
unnamed: 6.P$1 (2), D7.A
unnamed: 5.P$1 (2), D6.A
unnamed: 4.P$1 (2), D5.A
unnamed: 3.P$1 (2), D4.A
unnamed: 2.P$1 (2), D3.A
unnamed: 1.P$1 (2), D2.A
unnamed: D15.A, TAB.P$1 (2)
unnamed: D45.A, X.P$1 (2), X_1.P$1 (2)
unnamed: D28.A, \.P$1 (2)
unnamed: D27.A, ].P$1 (2)
unnamed: D26.A, [.P$1 (2)
unnamed: D25.A, P.P$1 (2)
unnamed: D24.A, O.P$1 (2)
unnamed: D23.A, I.P$1 (2)
unnamed: D22.A, U.P$1 (2)
unnamed: D21.A, Y.P$1 (2)
unnamed: D20.A, T.P$1 (2)
unnamed: D19.A, R.P$1 (2)
unnamed: D18.A, E.P$1 (2)
unnamed: D17.A, W.P$1 (2)
unnamed: D16.A, Q.P$1 (2)
unnamed: D47.A, V.P$1 (2), V_1.P$1 (2)
unnamed: ,.P$1 (2), ,_1.P$1 (2), D51.A
unnamed: D41.A, ENTER.P$1 (2), ISO_ENTER.P$1 (2)
unnamed: '.P$1 (2), D40.A
unnamed: COLON.P$1 (2), D39.A
unnamed: D38.A, L.P$1 (2)
unnamed: D37.A, K.P$1 (2)
unnamed: D36.A, J.P$1 (2)
unnamed: D35.A, H.P$1 (2)
unnamed: D34.A, G.P$1 (2)
unnamed: D33.A, F.P$1 (2)
unnamed: D.P$1 (2), D32.A
unnamed: D31.A, S.P$1 (2)
unnamed: A.P$1 (2), D30.A
unnamed: D42.A, L_1.25U_SHIFT.P$1 (2), L_2U_SHIFT.P$1 (2), L_SHIFT.P$1 (2)
unnamed: ..P$1 (2), ._1.P$1 (2), D52.A
unnamed: D67.A, EXTRA_1U_LEFT.P$1 (2), R_SHIFT.P$1 (2), R_SHIFT_1.75U_LEFT.P$1 (2), UP.P$1 (2)
unnamed: D68.A, U$2.S1, X5U_2.P$1 (2)
unnamed: D64.A, SPLIT_BS_2.P$1 (2), U$1.S1
unnamed: C5.1, R15.1, U$3.2 (VDD)
unnamed: #_ISO.P$1 (2), D43.A
unnamed: D44.A, Z.P$1 (2), Z_1.P$1 (2)
unnamed: B.P$1 (2), B_1.P$1 (2), D48.A
unnamed: C.P$1 (2), C_1.P$1 (2), D46.A
unnamed: D49.A, N.P$1 (2), N_1.P$1 (2)
unnamed: D50.A, M.P$1 (2), M_1.P$1 (2)
unnamed: D54.A, LCTRL.P$1 (2), LCTRL_1.5U.P$1 (2)
unnamed: /.P$1 (2), /_1.P$1 (2), D53.A
unnamed: 1U_4.P$1 (2), D61.A, FN.P$1 (2), R_CTRL_1.5U.P$1 (2)
unnamed: 1U_3.P$1 (2), D60.A, MENU_1U.P$1 (2), RCTRL.P$1 (2)
unnamed: 1U_2.P$1 (2), D59.A, MENU.P$1 (2), R_ALT_1.5.P$1 (2)
unnamed: 1U_1.P$1 (2), D58.A, RALT.P$1 (2)
unnamed: D57.A, SPACE_6.25U.P$1 (2), SPACE_7U.P$1 (2)
unnamed: D56.A, LALT.P$1 (2), LALT_1.5U.P$1 (2)
unnamed: D55.A, LWIN.P$1 (2), LWIN_1U.P$1 (2)
unnamed: FUSE.2, J3.VBUS1 (VBUS), J3.VBUS2 (VBUS)
unnamed: BS.P$1 (2), D14.A, SPLIT_BS_1.P$1 (2)
unnamed: D66.A, ISO_#.P$1 (2)
unnamed: J3.B5 (CC2), R11.2
unnamed: J3.A5 (CC1), R12.2
unnamed: R13.2, U$4.2 (PROG)
unnamed: LED2.C, R14.1
unnamed: R14.2, U$4.7 (!CHRG)
unnamed: C6.1, D63.1 (K), Q5.2 (S), U2.1 (VIN), U2.3 (EN)
unnamed: CAPS.P$1 (2), CAPS_STEP.P$1 (2), D29.A
unnamed: D65.A, R_SHIFT_1.75U_RIGHT.P$1 (2), X5U_1.P$1 (2)
POWER_PIN: IC3.P0.13
RESET: IC3.P0.14, IC3.P0.16, IC3.P0.18, PROG1.3, R2.2, U$62.C, U$62.D
ROW1: D1.C, D2.C, D3.C, D4.C, D5.C, D6.C, D7.C, D8.C, D9.C, D10.C, D11.C, D12.C, D13.C, D14.C, D64.C, IC3.P1.00
ROW2: D15.C, D16.C, D17.C, D18.C, D19.C, D20.C, D21.C, D22.C, D23.C, D24.C, D25.C, D26.C, D27.C, D28.C, IC3.P0.22
ROW3: D29.C, D30.C, D31.C, D32.C, D33.C, D34.C, D35.C, D36.C, D37.C, D38.C, D39.C, D40.C, D41.C, D66.C, IC3.P0.19
ROW4: D42.C, D43.C, D44.C, D45.C, D46.C, D47.C, D48.C, D49.C, D50.C, D51.C, D52.C, D53.C, D65.C, D67.C, D68.C, IC3.P0.21
ROW5: D54.C, D55.C, D56.C, D57.C, D58.C, D59.C, D60.C, D61.C, D62.C, IC3.P1.02
RXD: IC3.P0.08
SCK: IC3.SWDCLK, PROG1.4
SWD: IC3.SWDIO, PROG1.5
TXD: IC3.P0.06
VDD_NRF: D72.C, IC3.VDD_NRF, PROG1.1, R2.1, U2.5 (VOUT)
V_BATT: CN2.2, J4.1, Q5.3 (D), R15.2, R19.1, U$4.5 (BAT)
V_USB: C4.1, D63.2 (A), D71.C, FUSE.1, IC3.VBUS, J1.4, LED2.A, PROG1.6, Q5.1 (G), R17.2, U$4.4 (VCC), U$4.8 (CE)

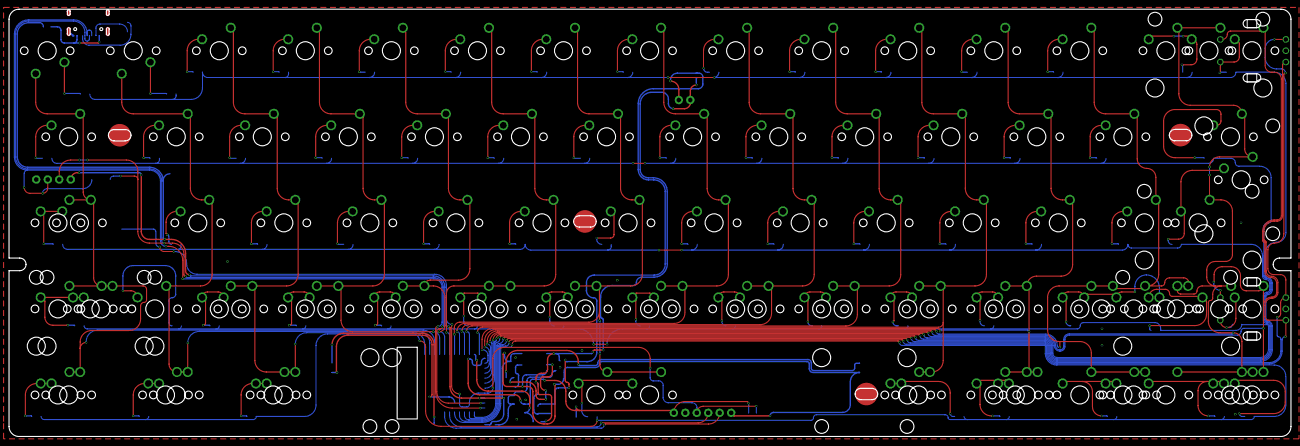
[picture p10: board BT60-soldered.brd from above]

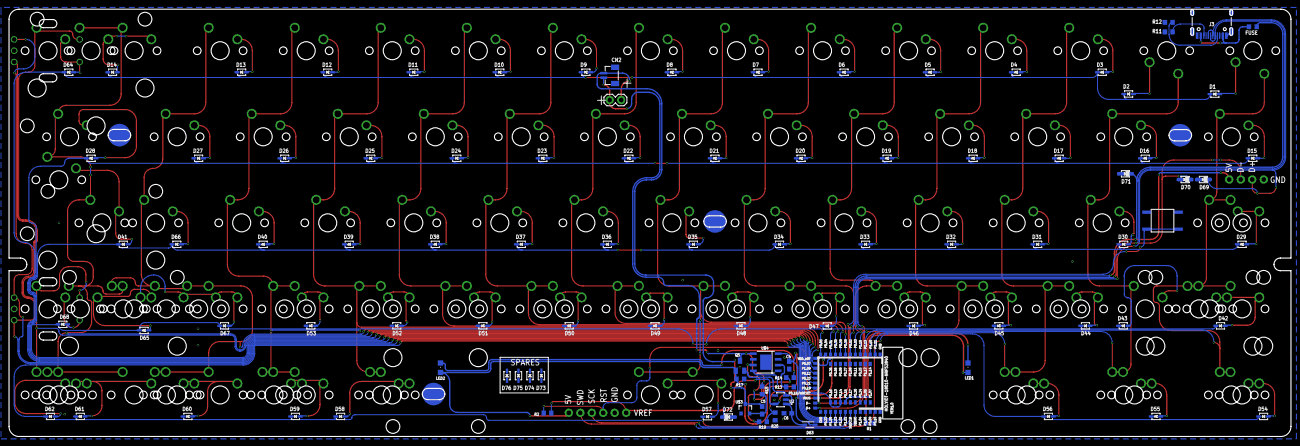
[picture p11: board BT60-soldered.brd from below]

Board: 2 copper layers, 283.8 x 94.6 mm, 214 parts (101 on the bottom side), 110 nets.

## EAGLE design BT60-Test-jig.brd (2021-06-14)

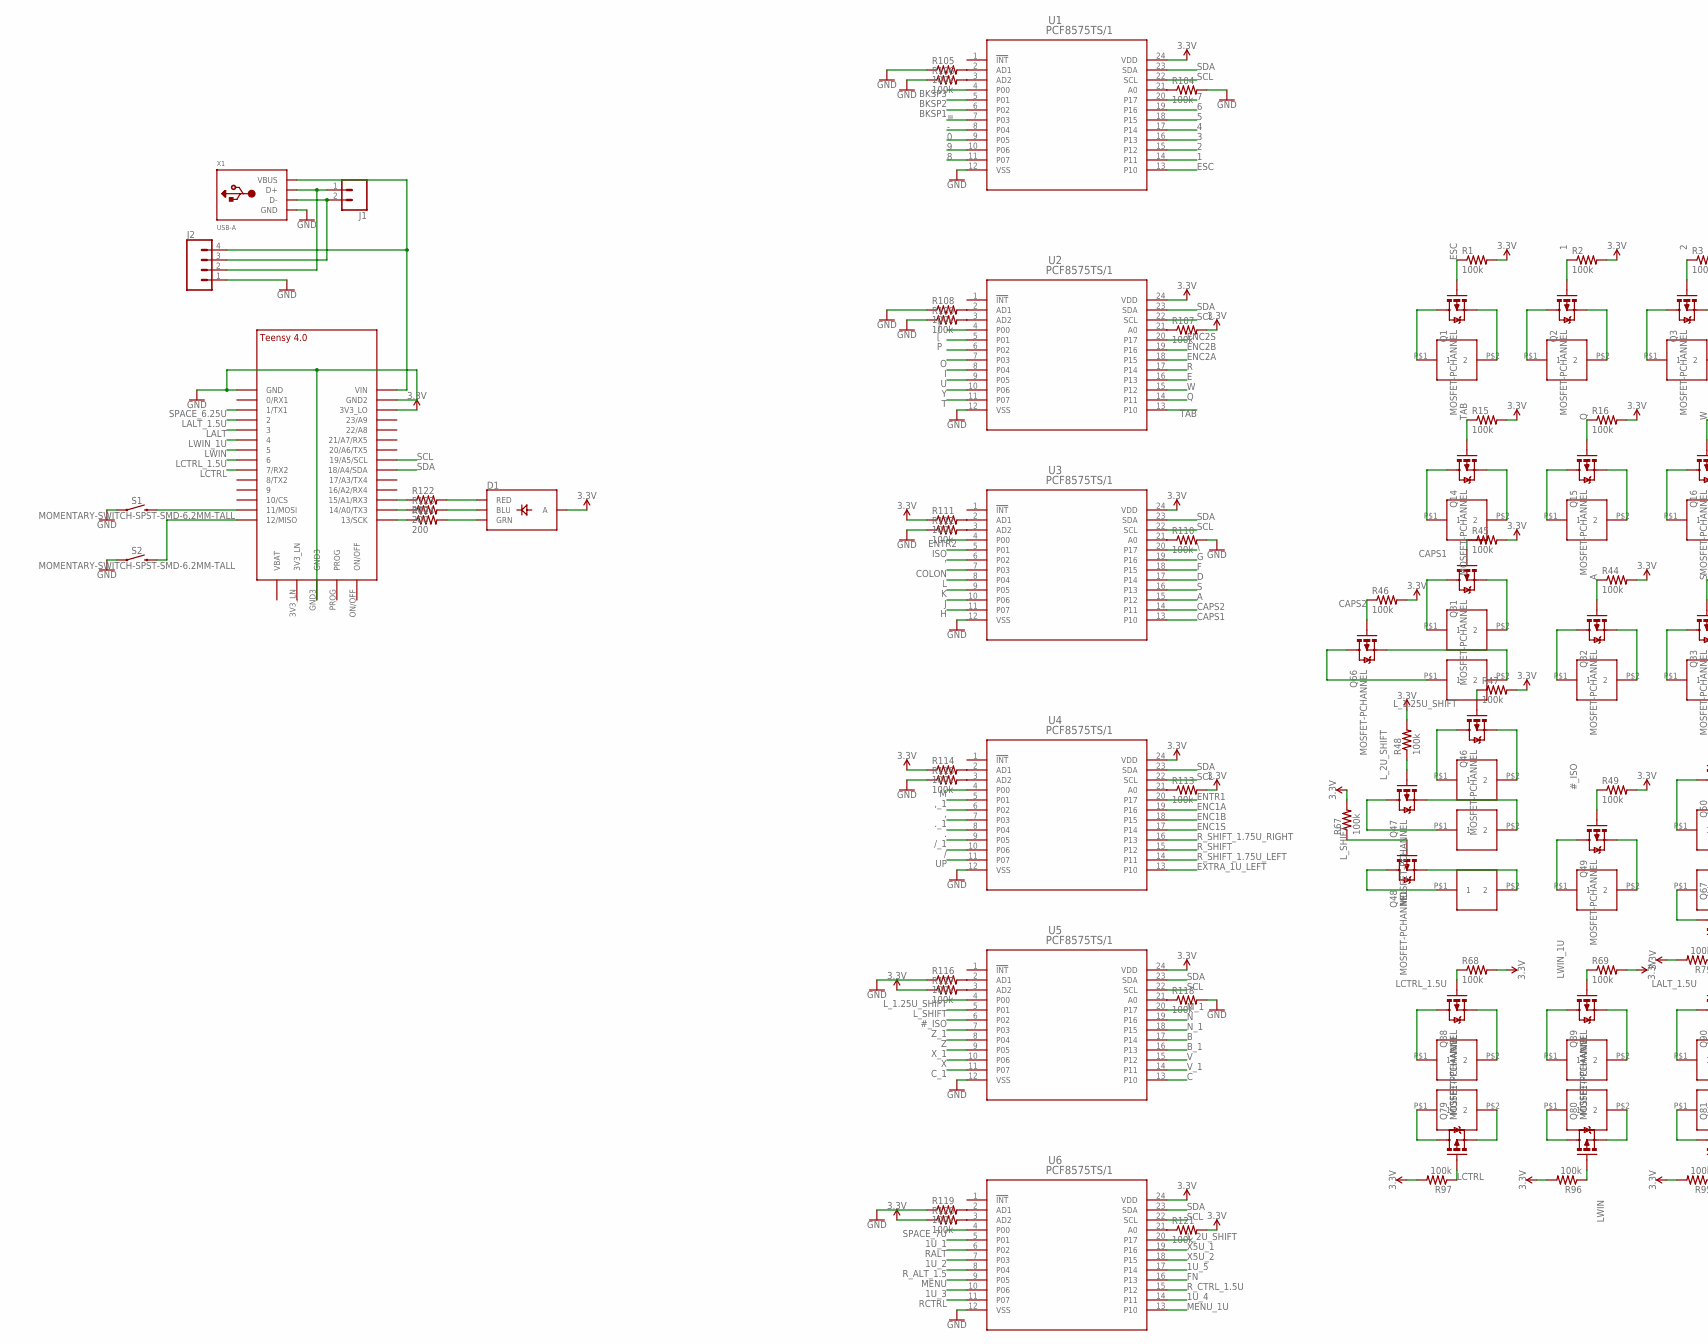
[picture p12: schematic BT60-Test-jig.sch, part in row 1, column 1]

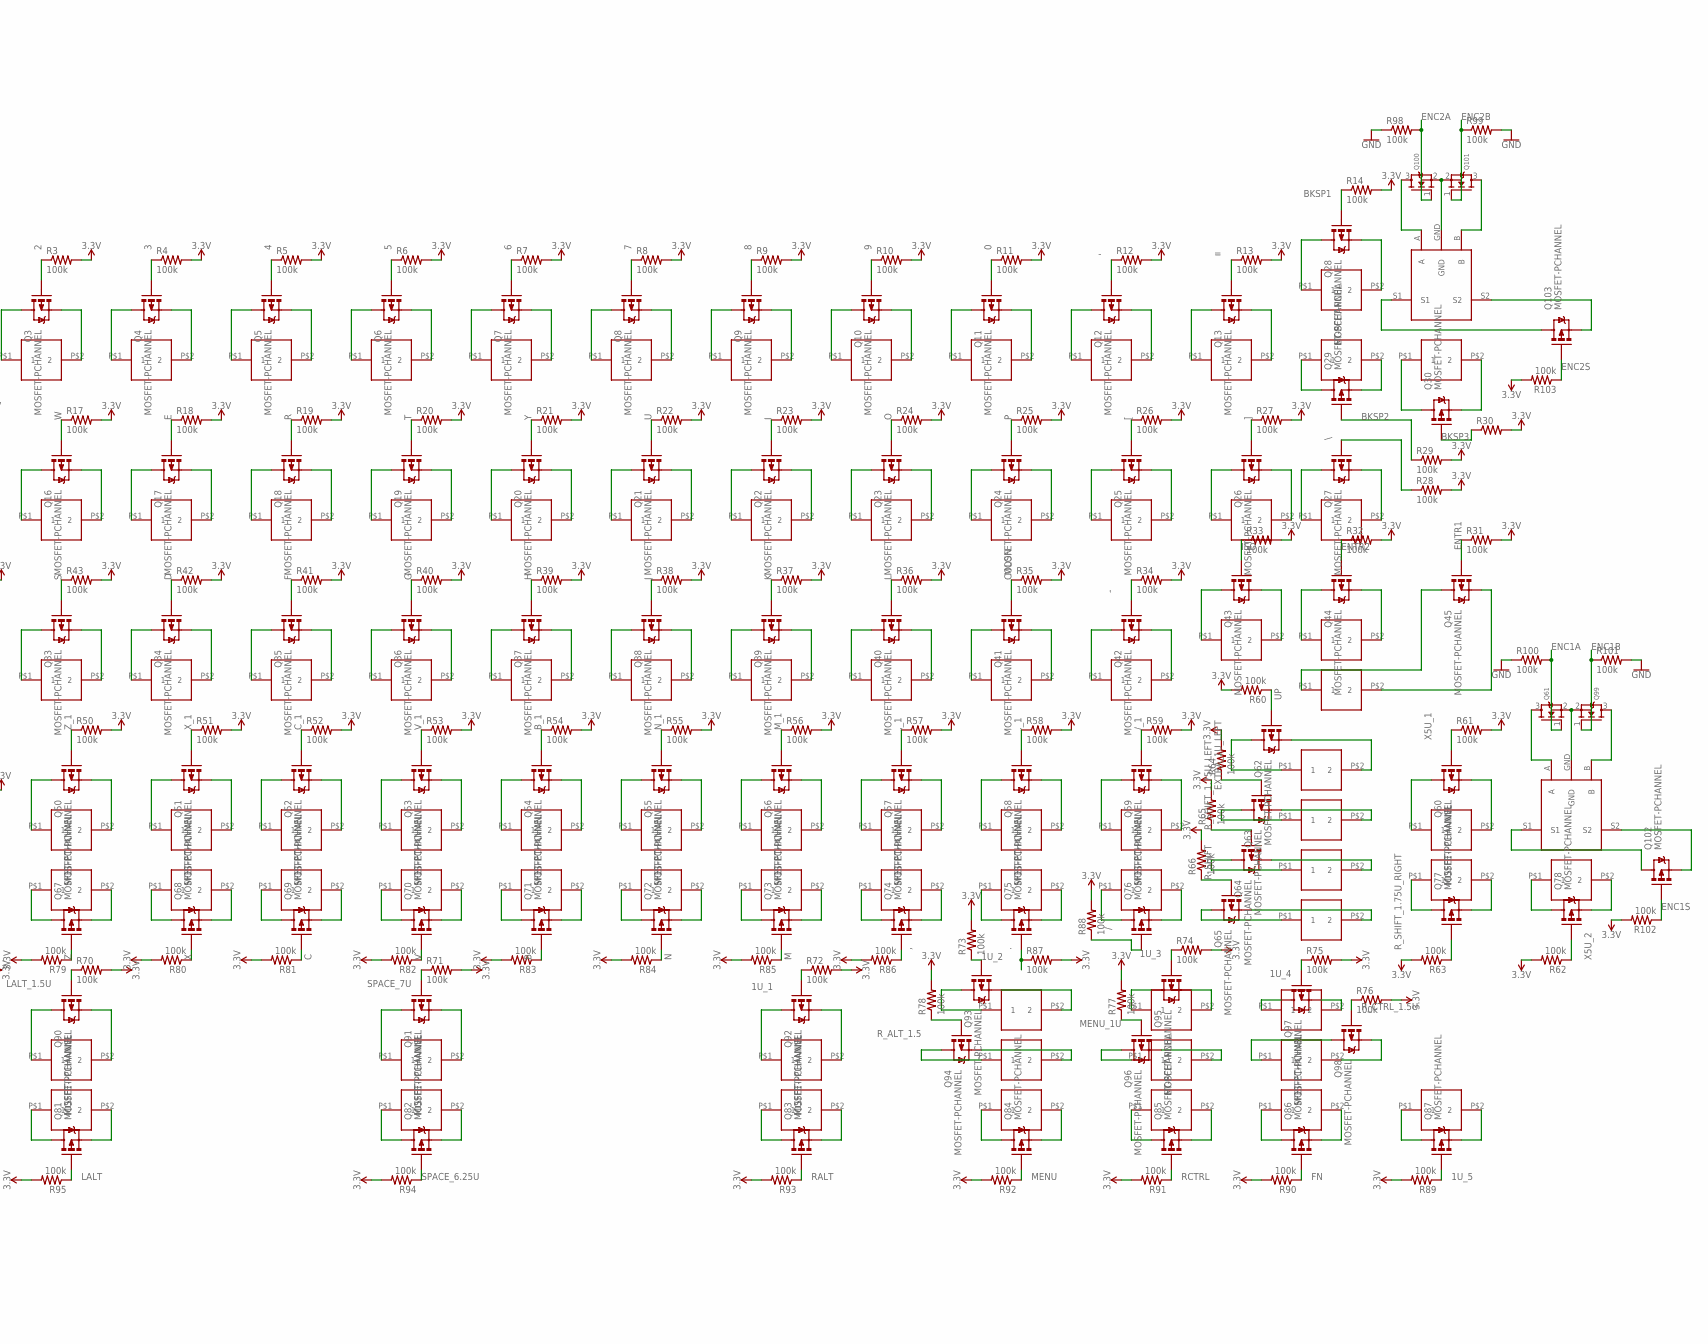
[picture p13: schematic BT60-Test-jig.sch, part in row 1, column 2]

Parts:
0, 1, 1U_1, 1U_2, 1U_3, 1U_4, 1U_5, 2, 3, 4, 5, 6, 7, 8, 9, ., ._1: CHERRY-SOLDERCHERRY-TEST; CHERRY-TEST
#_ISO: CHERRY-SOLDERCHERRY-TEST; CHERRY-TEST
': CHERRY-SOLDERCHERRY-TEST; CHERRY-TEST
,: CHERRY-SOLDERCHERRY-TEST; CHERRY-TEST
,_1: CHERRY-SOLDERCHERRY-TEST; CHERRY-TEST
-: CHERRY-SOLDERCHERRY-TEST; CHERRY-TEST
/: CHERRY-SOLDERCHERRY-TEST; CHERRY-TEST
/_1: CHERRY-SOLDERCHERRY-TEST; CHERRY-TEST
=: CHERRY-SOLDERCHERRY-TEST; CHERRY-TEST
A: CHERRY-SOLDERCHERRY-TEST; CHERRY-TEST
B: CHERRY-SOLDERCHERRY-TEST; CHERRY-TEST
BS: CHERRY-SOLDERCHERRY-TEST; CHERRY-TEST
B_1: CHERRY-SOLDERCHERRY-TEST; CHERRY-TEST
C: CHERRY-SOLDERCHERRY-TEST; CHERRY-TEST
CAPS: CHERRY-SOLDERCHERRY-TEST; CHERRY-TEST
CAPS_STEP: CHERRY-SOLDERCHERRY-TEST; CHERRY-TEST
COLON: CHERRY-SOLDERCHERRY-TEST; CHERRY-TEST
C_1: CHERRY-SOLDERCHERRY-TEST; CHERRY-TEST
D: CHERRY-SOLDERCHERRY-TEST; CHERRY-TEST
D1: LED-RGB-CASMD; LED-TRICOLOR-SMD
E: CHERRY-SOLDERCHERRY-TEST; CHERRY-TEST
ENTER: CHERRY-SOLDERCHERRY-TEST; CHERRY-TEST
ESC: CHERRY-SOLDERCHERRY-TEST; CHERRY-TEST
EXTRA_1U_LEFT: CHERRY-SOLDERCHERRY-TEST; CHERRY-TEST
F: CHERRY-SOLDERCHERRY-TEST; CHERRY-TEST
FN: CHERRY-SOLDERCHERRY-TEST; CHERRY-TEST
G: CHERRY-SOLDERCHERRY-TEST; CHERRY-TEST
H: CHERRY-SOLDERCHERRY-TEST; CHERRY-TEST
I: CHERRY-SOLDERCHERRY-TEST; CHERRY-TEST
ISO_#: CHERRY-SOLDERCHERRY-TEST; CHERRY-TEST
ISO_ENTER: CHERRY-SOLDERCHERRY-TEST; CHERRY-TEST
J: CHERRY-SOLDERCHERRY-TEST; CHERRY-TEST
J1: CONN_02; 1X02
J2: CONN_041X04_NO_SILK; 1X04_NO_SILK
K: CHERRY-SOLDERCHERRY-TEST; CHERRY-TEST
L: CHERRY-SOLDERCHERRY-TEST; CHERRY-TEST
LALT: CHERRY-SOLDERCHERRY-TEST; CHERRY-TEST
LALT_1.5U: CHERRY-SOLDERCHERRY-TEST; CHERRY-TEST
LCTRL: CHERRY-SOLDERCHERRY-TEST; CHERRY-TEST
LCTRL_1.5U: CHERRY-SOLDERCHERRY-TEST; CHERRY-TEST
LWIN: CHERRY-SOLDERCHERRY-TEST; CHERRY-TEST
LWIN_1U: CHERRY-SOLDERCHERRY-TEST; CHERRY-TEST
L_1.25U_SHIFT, L_2U_SHIFT: CHERRY-SOLDERCHERRY-TEST; CHERRY-TEST
L_SHIFT: CHERRY-SOLDERCHERRY-TEST; CHERRY-TEST
M: CHERRY-SOLDERCHERRY-TEST; CHERRY-TEST
MENU: CHERRY-SOLDERCHERRY-TEST; CHERRY-TEST
MENU_1U: CHERRY-SOLDERCHERRY-TEST; CHERRY-TEST
M_1: CHERRY-SOLDERCHERRY-TEST; CHERRY-TEST
N: CHERRY-SOLDERCHERRY-TEST; CHERRY-TEST
N_1: CHERRY-SOLDERCHERRY-TEST; CHERRY-TEST
O: CHERRY-SOLDERCHERRY-TEST; CHERRY-TEST
P: CHERRY-SOLDERCHERRY-TEST; CHERRY-TEST
Q: CHERRY-SOLDERCHERRY-TEST; CHERRY-TEST
Q1, Q2, Q3, Q4, Q5, Q6, Q7, Q8, Q9, Q10, Q11, Q12, Q13, Q14, Q15, Q16, Q17, Q18, Q19, Q20, Q21, Q22, Q23, Q24, Q25, Q26, Q27, Q28, Q29, Q30, Q31, Q32, Q33, Q34, Q35, Q36, Q37, Q38, Q39, Q40, Q41, Q42, Q43, Q44, Q45, Q46, Q47, Q48, Q49, Q50, Q51, Q52, Q53, Q54, Q55, Q56, Q57, Q58, Q59, Q60, Q62, Q63, Q64, Q65, Q66, Q67, Q68, Q69, Q70, Q71, Q72, Q73, Q74, Q75, Q76, Q77, Q78, Q79, Q80, Q81, Q82, Q83, Q84, Q85, Q86, Q87, Q88, Q89, Q90, Q91, Q92, Q93, Q94, Q95, Q96, Q97, Q98, Q102, Q103: MOSFET-PCHANNEL; SOT23-3
Q61, Q99, Q100, Q101: MOSFET-NREFLOW; SOT23
R: CHERRY-SOLDERCHERRY-TEST; CHERRY-TEST
R1, R2, R3, R4, R5, R6, R7, R8, R9, R10, R11, R12, R13, R14, R15, R16, R17, R18, R19, R20, R21, R22, R23, R24, R25, R26, R27, R28, R29, R30, R31, R32, R33, R34, R35, R36, R37, R38, R39, R40, R41, R42, R43, R44, R45, R46, R47, R48, R49, R50, R51, R52, R53, R54, R55, R56, R57, R58, R59, R60, R61, R62, R63, R64, R65, R66, R67, R68, R69, R70, R71, R72, R73, R74, R75, R76, R77, R78, R79, R80, R81, R82, R83, R84, R85, R86, R87, R88, R89, R90, R91, R92, R93, R94, R95, R96, R97, R98, R99, R100, R101, R102, R103, R104, R105, R106, R107, R108, R109, R110, R111, R112, R113, R114, R115, R116, R117, R118, R119, R120, R121: 100k; 0603-R
R122, R123, R124: 200; 0603-R
RALT: CHERRY-SOLDERCHERRY-TEST; CHERRY-TEST
RCTRL: CHERRY-SOLDERCHERRY-TEST; CHERRY-TEST
R_ALT_1.5: CHERRY-SOLDERCHERRY-TEST; CHERRY-TEST
R_CTRL_1.5U: CHERRY-SOLDERCHERRY-TEST; CHERRY-TEST
R_SHIFT: CHERRY-SOLDERCHERRY-TEST; CHERRY-TEST
R_SHIFT_1.75U_LEFT, R_SHIFT_1.75U_RIGHT: CHERRY-SOLDERCHERRY-TEST; CHERRY-TEST
S: CHERRY-SOLDERCHERRY-TEST; CHERRY-TEST
S1, S2: MOMENTARY-SWITCH-SPST-SMD-6.2MM-TALL; TACTILE_SWITCH_SMD_6.2MM_TALL
SPACE_6.25U, SPACE_7U: CHERRY-SOLDERCHERRY-TEST; CHERRY-TEST
SPLIT_BS_1, SPLIT_BS_2: CHERRY-SOLDERCHERRY-TEST; CHERRY-TEST
T: CHERRY-SOLDERCHERRY-TEST; CHERRY-TEST
TAB: CHERRY-SOLDERCHERRY-TEST; CHERRY-TEST
U: CHERRY-SOLDERCHERRY-TEST; CHERRY-TEST
U1, U2, U3, U4, U5, U6: PCF8575TS/1; SOT340-1_NXP
U$1, U$3: ENCODER
U$2: TEENSY_4.0
UP: CHERRY-SOLDERCHERRY-TEST; CHERRY-TEST
V: CHERRY-SOLDERCHERRY-TEST; CHERRY-TEST
V_1: CHERRY-SOLDERCHERRY-TEST; CHERRY-TEST
W: CHERRY-SOLDERCHERRY-TEST; CHERRY-TEST
X, X5U_1, X5U_2: CHERRY-SOLDERCHERRY-TEST; CHERRY-TEST
X1: USB-A; MOLEX_480371000
X_1: CHERRY-SOLDERCHERRY-TEST; CHERRY-TEST
Y: CHERRY-SOLDERCHERRY-TEST; CHERRY-TEST
Z: CHERRY-SOLDERCHERRY-TEST; CHERRY-TEST
Z_1: CHERRY-SOLDERCHERRY-TEST; CHERRY-TEST
[: CHERRY-SOLDERCHERRY-TEST; CHERRY-TEST
\: CHERRY-SOLDERCHERRY-TEST; CHERRY-TEST
]: CHERRY-SOLDERCHERRY-TEST; CHERRY-TEST

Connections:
0: Q11.1 (G), R11.1, U1.9 (P05)
1: Q2.1 (G), R2.1, U1.14 (P11)
1U_1: Q92.1 (G), R72.1, U6.5 (P01)
1U_2: Q93.1 (G), R73.1, U6.7 (P03)
1U_3: Q95.1 (G), R74.1, U6.10 (P06)
1U_4: Q97.1 (G), R75.1, U6.14 (P11)
1U_5: Q87.1 (G), R89.1, U6.17 (P14)
2: Q3.1 (G), R3.1, U1.15 (P12)
3: Q4.1 (G), R4.1, U1.16 (P13)
3.3V: D1.A, R1.2, R2.2, R3.2, R4.2, R5.2, R6.2, R7.2, R8.2, R9.2, R10.2, R11.2, R12.2, R13.2, R14.2, R15.2, R16.2, R17.2, R18.2, R19.2, R20.2, R21.2, R22.2, R23.2, R24.2, R25.2, R26.2, R27.2, R28.2, R29.2, R30.2, R31.2, R32.2, R33.2, R34.2, R35.2, R36.2, R37.2, R38.2, R39.2, R40.2, R41.2, R42.2, R43.2, R44.2, R45.2, R46.2, R47.2, R48.2, R49.2, R50.2, R51.2, R52.2, R53.2, R54.2, R55.2, R56.2, R57.2, R58.2, R59.2, R60.2, R61.2, R62.2, R63.2, R64.2, R65.2, R66.2, R67.2, R68.2, R69.2, R70.2, R71.2, R72.2, R73.2, R74.2, R75.2, R76.2, R77.2, R78.2, R79.2, R80.2, R81.2, R82.2, R83.2, R84.2, R85.2, R86.2, R87.2, R88.2, R89.2, R90.2, R91.2, R92.2, R93.2, R94.2, R95.2, R96.2, R97.2, R102.2, R103.2, R107.2, R111.1, R113.2, R114.1, R117.1, R120.1, R121.2, U1.24 (VDD), U2.24 (VDD), U3.24 (VDD), U4.24 (VDD), U5.24 (VDD), U6.24 (VDD), U$2.3V3_LO
4: Q5.1 (G), R5.1, U1.17 (P14)
5: Q6.1 (G), R6.1, U1.18 (P15)
6: Q7.1 (G), R7.1, U1.19 (P16)
7: Q8.1 (G), R8.1, U1.20 (P17)
8: Q9.1 (G), R9.1, U1.11 (P07)
9: Q10.1 (G), R10.1, U1.10 (P06)
#_ISO: Q49.1 (G), R49.1, U5.6 (P02)
': Q42.1 (G), R34.1, U3.6 (P02)
,: Q74.1 (G), R86.1, U4.6 (P02)
,_1: Q57.1 (G), R57.1, U4.5 (P01)
-: Q12.1 (G), R12.1, U1.8 (P04)
.: Q75.1 (G), R87.1, U4.8 (P04)
._1: Q58.1 (G), R58.1, U4.7 (P03)
/: Q76.1 (G), R88.1, U4.10 (P06)
/_1: Q59.1 (G), R59.1, U4.9 (P05)
=: Q13.1 (G), R13.1, U1.7 (P03)
A: Q32.1 (G), R44.1, U3.15 (P12)
B: Q71.1 (G), R83.1, U5.17 (P14)
BKSP1: Q28.1 (G), R14.1, U1.6 (P02)
BKSP2: Q29.1 (G), R29.1, U1.5 (P01)
BKSP3: Q30.1 (G), R30.1, U1.4 (P00)
B_1: Q54.1 (G), R54.1, U5.16 (P13)
C: Q69.1 (G), R81.1, U5.13 (P10)
CAPS1: Q31.1 (G), R45.1, U3.13 (P10)
CAPS2: Q66.1 (G), R46.1, U3.14 (P11)
COLON: Q41.1 (G), R35.1, U3.7 (P03)
C_1: Q52.1 (G), R52.1, U5.11 (P07)
D: Q34.1 (G), R42.1, U3.17 (P14)
E: Q17.1 (G), R18.1, U2.16 (P13)
ENC1A: Q61.1 (G), R100.2, U4.19 (P16)
ENC1B: Q99.1 (G), R101.1, U4.18 (P15)
ENC1S: Q102.1 (G), R102.1, U4.17 (P14)
ENC2A: Q100.1 (G), R98.2, U2.18 (P15)
ENC2B: Q101.1 (G), R99.1, U2.19 (P16)
ENC2S: Q103.1 (G), R103.1, U2.20 (P17)
ENTR1: Q45.1 (G), R31.1, U4.20 (P17)
ENTR2: Q44.1 (G), R32.1, U3.4 (P00)
ESC: Q1.1 (G), R1.1, U1.13 (P10)
EXTRA_1U_LEFT: Q63.1 (G), R64.1, U4.13 (P10)
F: Q35.1 (G), R41.1, U3.18 (P15)
FN: Q86.1 (G), R90.1, U6.16 (P13)
G: Q36.1 (G), R40.1, U3.19 (P16)
GND: J2.1, R98.1, R99.2, R100.1, R101.2, R104.2, R105.1, R106.1, R108.1, R109.1, R110.2, R112.1, R115.1, R116.1, R118.2, R119.1, S1.A2 (1), S2.A2 (1), U1.12 (VSS), U2.12 (VSS), U3.12 (VSS), U4.12 (VSS), U5.12 (VSS), U6.12 (VSS), U$2.GND, U$2.GND2, U$2.GND3, X1.4 (GND)
H: Q37.1 (G), R39.1, U3.11 (P07)
I: Q22.1 (G), R23.1, U2.8 (P04)
ISO: Q43.1 (G), R33.1, U3.5 (P01)
J: Q38.1 (G), R38.1, U3.10 (P06)
K: Q39.1 (G), R37.1, U3.9 (P05)
L: Q40.1 (G), R36.1, U3.8 (P04)
LALT: Q81.1 (G), R95.1, U$2.3/CANTX (3)
LALT_1.5U: Q90.1 (G), R70.1, U$2.2
LCTRL: Q79.1 (G), R97.1, U$2.7 (7/RX2)
LCTRL_1.5U: Q88.1 (G), R68.1, U$2.6
LWIN: Q80.1 (G), R96.1, U$2.5
LWIN_1U: Q89.1 (G), R69.1, U$2.4/CANRX (4)
L_1.25U_SHIFT: Q46.1 (G), R47.1, U5.4 (P00)
L_2U_SHIFT: Q47.1 (G), R48.1, U6.20 (P17)
L_SHIFT: Q48.1 (G), R67.1, U5.5 (P01)
M: Q73.1 (G), R85.1, U4.4 (P00)
MENU: Q84.1 (G), R92.1, U6.9 (P05)
MENU_1U: Q96.1 (G), R77.1, U6.13 (P10)
M_1: Q56.1 (G), R56.1, U5.20 (P17)
N: Q72.1 (G), R84.1, U5.19 (P16)
unnamed: ESC.P$1 (1), Q1.3 (D)
unnamed: ESC.P$2 (2), Q1.2 (S)
unnamed: 1.P$1 (1), Q2.3 (D)
unnamed: 1.P$2 (2), Q2.2 (S)
unnamed: 2.P$1 (1), Q3.3 (D)
unnamed: 2.P$2 (2), Q3.2 (S)
unnamed: 3.P$1 (1), Q4.3 (D)
unnamed: 3.P$2 (2), Q4.2 (S)
unnamed: 4.P$1 (1), Q5.3 (D)
unnamed: 4.P$2 (2), Q5.2 (S)
unnamed: 5.P$1 (1), Q6.3 (D)
unnamed: 5.P$2 (2), Q6.2 (S)
unnamed: 6.P$1 (1), Q7.3 (D)
unnamed: 6.P$2 (2), Q7.2 (S)
unnamed: 7.P$1 (1), Q8.3 (D)
unnamed: 7.P$2 (2), Q8.2 (S)
unnamed: 8.P$1 (1), Q9.3 (D)
unnamed: 8.P$2 (2), Q9.2 (S)
unnamed: 9.P$1 (1), Q10.3 (D)
unnamed: 9.P$2 (2), Q10.2 (S)
unnamed: 0.P$1 (1), Q11.3 (D)
unnamed: 0.P$2 (2), Q11.2 (S)
unnamed: -.P$1 (1), Q12.3 (D)
unnamed: -.P$2 (2), Q12.2 (S)
unnamed: =.P$1 (1), Q13.3 (D)
unnamed: =.P$2 (2), Q13.2 (S)
unnamed: Q14.3 (D), TAB.P$1 (1)
unnamed: Q14.2 (S), TAB.P$2 (2)
unnamed: Q.P$1 (1), Q15.3 (D)
unnamed: Q.P$2 (2), Q15.2 (S)
unnamed: Q16.3 (D), W.P$1 (1)
unnamed: Q16.2 (S), W.P$2 (2)
unnamed: E.P$1 (1), Q17.3 (D)
unnamed: E.P$2 (2), Q17.2 (S)
unnamed: Q18.3 (D), R.P$1 (1)
unnamed: Q18.2 (S), R.P$2 (2)
unnamed: Q19.3 (D), T.P$1 (1)
unnamed: Q19.2 (S), T.P$2 (2)
unnamed: Q20.3 (D), Y.P$1 (1)
unnamed: Q20.2 (S), Y.P$2 (2)
unnamed: Q21.3 (D), U.P$1 (1)
unnamed: Q21.2 (S), U.P$2 (2)
unnamed: I.P$1 (1), Q22.3 (D)
unnamed: I.P$2 (2), Q22.2 (S)
unnamed: O.P$1 (1), Q23.3 (D)
unnamed: O.P$2 (2), Q23.2 (S)
unnamed: P.P$1 (1), Q24.3 (D)
unnamed: P.P$2 (2), Q24.2 (S)
unnamed: Q25.3 (D), [.P$1 (1)
unnamed: Q25.2 (S), [.P$2 (2)
unnamed: Q26.3 (D), ].P$1 (1)
unnamed: Q26.2 (S), ].P$2 (2)
unnamed: Q27.3 (D), \.P$1 (1)
unnamed: Q27.2 (S), \.P$2 (2)
unnamed: Q28.3 (D), SPLIT_BS_1.P$1 (1)
unnamed: Q28.2 (S), SPLIT_BS_1.P$2 (2)
unnamed: BS.P$2 (2), Q29.2 (S)
unnamed: BS.P$1 (1), Q29.3 (D)
unnamed: Q30.2 (S), SPLIT_BS_2.P$2 (2)
unnamed: Q30.3 (D), SPLIT_BS_2.P$1 (1)
unnamed: CAPS_STEP.P$1 (1), Q31.3 (D)
unnamed: CAPS_STEP.P$2 (2), Q31.2 (S)
unnamed: A.P$1 (1), Q32.3 (D)
unnamed: A.P$2 (2), Q32.2 (S)
unnamed: Q33.3 (D), S.P$1 (1)
unnamed: Q33.2 (S), S.P$2 (2)
unnamed: D.P$1 (1), Q34.3 (D)
unnamed: D.P$2 (2), Q34.2 (S)
unnamed: F.P$1 (1), Q35.3 (D)
unnamed: F.P$2 (2), Q35.2 (S)
unnamed: G.P$1 (1), Q36.3 (D)
unnamed: G.P$2 (2), Q36.2 (S)
unnamed: H.P$1 (1), Q37.3 (D)
unnamed: H.P$2 (2), Q37.2 (S)
unnamed: J.P$1 (1), Q38.3 (D)
unnamed: J.P$2 (2), Q38.2 (S)
unnamed: K.P$1 (1), Q39.3 (D)
unnamed: K.P$2 (2), Q39.2 (S)
unnamed: L.P$1 (1), Q40.3 (D)
unnamed: L.P$2 (2), Q40.2 (S)
unnamed: COLON.P$1 (1), Q41.3 (D)
unnamed: COLON.P$2 (2), Q41.2 (S)
unnamed: '.P$1 (1), Q42.3 (D)
unnamed: '.P$2 (2), Q42.2 (S)
unnamed: ISO_#.P$1 (1), Q43.3 (D)
unnamed: ISO_#.P$2 (2), Q43.2 (S)
unnamed: ISO_ENTER.P$1 (1), Q44.3 (D)
unnamed: ISO_ENTER.P$2 (2), Q44.2 (S)
unnamed: ENTER.P$1 (1), Q45.3 (D)
unnamed: ENTER.P$2 (2), Q45.2 (S)
unnamed: L_1.25U_SHIFT.P$1 (1), Q46.3 (D)
unnamed: L_1.25U_SHIFT.P$2 (2), Q46.2 (S)
unnamed: L_2U_SHIFT.P$1 (1), Q47.3 (D)
unnamed: L_2U_SHIFT.P$2 (2), Q47.2 (S)
unnamed: L_SHIFT.P$1 (1), Q48.3 (D)
unnamed: L_SHIFT.P$2 (2), Q48.2 (S)
unnamed: #_ISO.P$1 (1), Q49.3 (D)
unnamed: #_ISO.P$2 (2), Q49.2 (S)
unnamed: Q50.3 (D), Z_1.P$1 (1)
unnamed: Q50.2 (S), Z_1.P$2 (2)
unnamed: Q51.3 (D), X_1.P$1 (1)
unnamed: Q51.2 (S), X_1.P$2 (2)
unnamed: C_1.P$1 (1), Q52.3 (D)
unnamed: C_1.P$2 (2), Q52.2 (S)
unnamed: Q53.3 (D), V_1.P$1 (1)
unnamed: Q53.2 (S), V_1.P$2 (2)
unnamed: B_1.P$1 (1), Q54.3 (D)
unnamed: B_1.P$2 (2), Q54.2 (S)
unnamed: N_1.P$1 (1), Q55.3 (D)
unnamed: N_1.P$2 (2), Q55.2 (S)
unnamed: M_1.P$1 (1), Q56.3 (D)
unnamed: M_1.P$2 (2), Q56.2 (S)
unnamed: ,_1.P$1 (1), Q57.3 (D)
unnamed: ,_1.P$2 (2), Q57.2 (S)
unnamed: ._1.P$1 (1), Q58.3 (D)
unnamed: ._1.P$2 (2), Q58.2 (S)
unnamed: /_1.P$1 (1), Q59.3 (D)
unnamed: /_1.P$2 (2), Q59.2 (S)
unnamed: Q60.3 (D), X5U_1.P$1 (1)
unnamed: Q60.2 (S), X5U_1.P$2 (2)
unnamed: Q61.2 (S), Q99.2 (S), U$3.GND
unnamed: Q61.3 (D), U$3.A
unnamed: Q62.3 (D), UP.P$1 (1)
unnamed: Q62.2 (S), UP.P$2 (2)
unnamed: EXTRA_1U_LEFT.P$1 (1), Q63.3 (D)
unnamed: EXTRA_1U_LEFT.P$2 (2), Q63.2 (S)
unnamed: Q64.3 (D), R_SHIFT_1.75U_LEFT.P$1 (1)
unnamed: Q64.2 (S), R_SHIFT_1.75U_LEFT.P$2 (2)
unnamed: Q65.3 (D), R_SHIFT.P$1 (1)
unnamed: Q65.2 (S), R_SHIFT.P$2 (2)
unnamed: CAPS.P$1 (1), Q66.3 (D)
unnamed: CAPS.P$2 (2), Q66.2 (S)
unnamed: Q67.2 (S), Z.P$2 (2)
unnamed: Q67.3 (D), Z.P$1 (1)
unnamed: Q68.2 (S), X.P$2 (2)
unnamed: Q68.3 (D), X.P$1 (1)
unnamed: C.P$2 (2), Q69.2 (S)
unnamed: C.P$1 (1), Q69.3 (D)
unnamed: Q70.2 (S), V.P$2 (2)
unnamed: Q70.3 (D), V.P$1 (1)
unnamed: B.P$2 (2), Q71.2 (S)
unnamed: B.P$1 (1), Q71.3 (D)
unnamed: N.P$2 (2), Q72.2 (S)
unnamed: N.P$1 (1), Q72.3 (D)
unnamed: M.P$2 (2), Q73.2 (S)
unnamed: M.P$1 (1), Q73.3 (D)
unnamed: ,.P$2 (2), Q74.2 (S)
unnamed: ,.P$1 (1), Q74.3 (D)
unnamed: ..P$2 (2), Q75.2 (S)
unnamed: ..P$1 (1), Q75.3 (D)
unnamed: /.P$2 (2), Q76.2 (S)
unnamed: /.P$1 (1), Q76.3 (D)
unnamed: Q77.2 (S), R_SHIFT_1.75U_RIGHT.P$2 (2)
unnamed: Q77.3 (D), R_SHIFT_1.75U_RIGHT.P$1 (1)
unnamed: Q78.2 (S), X5U_2.P$2 (2)
unnamed: Q78.3 (D), X5U_2.P$1 (1)
unnamed: LCTRL.P$2 (2), Q79.2 (S)
unnamed: LCTRL.P$1 (1), Q79.3 (D)
unnamed: LWIN.P$2 (2), Q80.2 (S)
unnamed: LWIN.P$1 (1), Q80.3 (D)
unnamed: LALT.P$2 (2), Q81.2 (S)
unnamed: LALT.P$1 (1), Q81.3 (D)
unnamed: Q82.2 (S), SPACE_6.25U.P$2 (2)
unnamed: Q82.3 (D), SPACE_6.25U.P$1 (1)
unnamed: Q83.2 (S), RALT.P$2 (2)
unnamed: Q83.3 (D), RALT.P$1 (1)
unnamed: MENU.P$2 (2), Q84.2 (S)
unnamed: MENU.P$1 (1), Q84.3 (D)
unnamed: Q85.2 (S), RCTRL.P$2 (2)
unnamed: Q85.3 (D), RCTRL.P$1 (1)
unnamed: FN.P$2 (2), Q86.2 (S)
unnamed: FN.P$1 (1), Q86.3 (D)
unnamed: 1U_5.P$2 (2), Q87.2 (S)
unnamed: 1U_5.P$1 (1), Q87.3 (D)
unnamed: LCTRL_1.5U.P$1 (1), Q88.3 (D)
unnamed: LCTRL_1.5U.P$2 (2), Q88.2 (S)
unnamed: LWIN_1U.P$1 (1), Q89.3 (D)
unnamed: LWIN_1U.P$2 (2), Q89.2 (S)
unnamed: LALT_1.5U.P$1 (1), Q90.3 (D)
unnamed: LALT_1.5U.P$2 (2), Q90.2 (S)
unnamed: Q91.3 (D), SPACE_7U.P$1 (1)
unnamed: Q91.2 (S), SPACE_7U.P$2 (2)
unnamed: 1U_1.P$1 (1), Q92.3 (D)
unnamed: 1U_1.P$2 (2), Q92.2 (S)
unnamed: 1U_2.P$1 (1), Q93.3 (D)
unnamed: 1U_2.P$2 (2), Q93.2 (S)
unnamed: Q94.3 (D), R_ALT_1.5.P$1 (1)
unnamed: Q94.2 (S), R_ALT_1.5.P$2 (2)
unnamed: 1U_3.P$1 (1), Q95.3 (D)
unnamed: 1U_3.P$2 (2), Q95.2 (S)
unnamed: MENU_1U.P$1 (1), Q96.3 (D)
unnamed: MENU_1U.P$2 (2), Q96.2 (S)
unnamed: 1U_4.P$1 (1), Q97.3 (D)
unnamed: 1U_4.P$2 (2), Q97.2 (S)
unnamed: Q98.3 (D), R_CTRL_1.5U.P$1 (1)
unnamed: Q98.2 (S), R_CTRL_1.5U.P$2 (2)
unnamed: Q99.3 (D), U$3.B
unnamed: Q100.2 (S), Q101.2 (S), U$1.GND
unnamed: Q100.3 (D), U$1.A
unnamed: Q101.3 (D), U$1.B
unnamed: Q103.3 (D), U$1.S1
unnamed: Q103.2 (S), U$1.S2
unnamed: Q102.3 (D), U$3.S1
unnamed: Q102.2 (S), U$3.S2
unnamed: R104.1, U1.21 (A0)
unnamed: R105.2, U1.2 (AD1)
unnamed: R106.2, U1.3 (AD2)
unnamed: R107.1, U2.21 (A0)
unnamed: R108.2, U2.2 (AD1)
unnamed: R109.2, U2.3 (AD2)
unnamed: R111.2, U3.2 (AD1)
unnamed: R112.2, U3.3 (AD2)
unnamed: R110.1, U3.21 (A0)
unnamed: R113.1, U4.21 (A0)
unnamed: R114.2, U4.2 (AD1)
unnamed: R115.2, U4.3 (AD2)
unnamed: R116.2, U5.2 (AD1)
unnamed: R117.2, U5.3 (AD2)
unnamed: R118.1, U5.21 (A0)
unnamed: J2.4, U$2.VIN, X1.1 (VBUS)
unnamed: J1.1, J2.2, X1.3 (D+)
unnamed: J1.2, J2.3, X1.2 (D-)
unnamed: D1.R (RED), R122.2
unnamed: D1.B (BLU), R123.2
unnamed: D1.G (GRN), R124.2
unnamed: R124.1, U$2.13/SCK
unnamed: R123.1, U$2.14/A0 (14/A0/TX3)
unnamed: R122.1, U$2.15/A1 (15/A1/RX3)
unnamed: S1.B2 (2), U$2.11/MOSI
unnamed: S2.B2 (2), U$2.12/MISO
unnamed: R119.2, U6.2 (AD1)
unnamed: R120.2, U6.3 (AD2)
unnamed: R121.1, U6.21 (A0)
N_1: Q55.1 (G), R55.1, U5.18 (P15)
O: Q23.1 (G), R24.1, U2.7 (P03)
P: Q24.1 (G), R25.1, U2.6 (P02)
Q: Q15.1 (G), R16.1, U2.14 (P11)
R: Q18.1 (G), R19.1, U2.17 (P14)
RALT: Q83.1 (G), R93.1, U6.6 (P02)
RCTRL: Q85.1 (G), R91.1, U6.11 (P07)
R_ALT_1.5: Q94.1 (G), R78.1, U6.8 (P04)
R_CTRL_1.5U: Q98.1 (G), R76.1, U6.15 (P12)
R_SHIFT: Q65.1 (G), R66.1, U4.15 (P12)
R_SHIFT_1.75U_LEFT: Q64.1 (G), R65.1, U4.14 (P11)
R_SHIFT_1.75U_RIGHT: Q77.1 (G), R63.1, U4.16 (P13)
S: Q33.1 (G), R43.1, U3.16 (P13)
SCL: U1.22 (SCL), U2.22 (SCL), U3.22 (SCL), U4.22 (SCL), U5.22 (SCL), U6.22 (SCL), U$2.19/A5/SCL
SDA: U1.23 (SDA), U2.23 (SDA), U3.23 (SDA), U4.23 (SDA), U5.23 (SDA), U6.23 (SDA), U$2.18/A4/SDA
SPACE_6.25U: Q82.1 (G), R94.1, U$2.1/TX (1/TX1)
SPACE_7U: Q91.1 (G), R71.1, U6.4 (P00)
T: Q19.1 (G), R20.1, U2.11 (P07)
TAB: Q14.1 (G), R15.1, U2.13 (P10)
U: Q21.1 (G), R22.1, U2.9 (P05)
UP: Q62.1 (G), R60.1, U4.11 (P07)
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

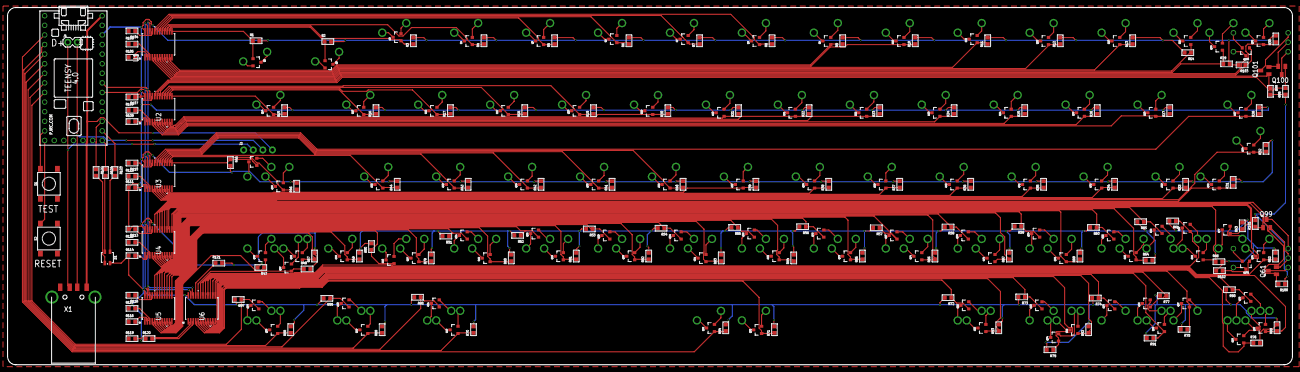
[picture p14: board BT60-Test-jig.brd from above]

Board: 2 copper layers, 340.3 x 94.6 mm, 339 parts (0 on the bottom side), 340 nets.

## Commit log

2020-12-14 initial upload
    [CRBN 60.brd, CRBN 60.dxf, CRBN 60.sch]
2020-12-27 tweaks and checks
    [CRBN 60.brd, CRBN 60.sch]
2020-12-30 tweaksa for erc
    [CRBN 60.sch]
2021-02-05 new board
    [CRBN 60.brd, CRBN 60.sch]
2021-02-26 latest revision
    [CRBN-60.brd, CRBN-60.sch]
2021-02-26 library updates
    [CRBN-60.brd]
2021-03-04 soldered version
    [CRBN-60-soldered.brd, CRBN-60-soldered.sch]
2021-06-14 bt60 test jig upload
    [BT60-Test-jig.brd, BT60-Test-jig.sch]
2021-08-03 Final update before release
    [CRBN-60-soldered.sch]
2021-11-23 Tidy up for release
    [BT60-soldered.brd, BT60-soldered.sch, BT60.brd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]
2021-11-23 further release tweaks
    [BT60-soldered.brd, BT60-soldered.sch]
2021-12-30 Schematic Update
    [BT60.brd]

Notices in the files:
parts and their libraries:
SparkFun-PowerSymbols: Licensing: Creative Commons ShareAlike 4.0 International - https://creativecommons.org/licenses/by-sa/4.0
